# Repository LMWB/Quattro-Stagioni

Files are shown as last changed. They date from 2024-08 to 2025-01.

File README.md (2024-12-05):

# Quattro-Stagioni
RTD-Sensor Breakoutboard and C-Library

# Abstract
RTD stands for Resistance Temperature Detector. Most common used versions are PT100, PT1000 and KTY.

RTD Messverfahren werden von IC's implementiert wie z.B. der ADS124 von TI. Mit ca. 10€ sind diese jedoch verhaeltnismaessig preisintensiv.
RDT-Sensoren werden typischerweise mit einem konstanten Strom um die 1mA beaufschlagt und der daraus resultierende Spannungsfall wird gemessen.
Die spezifische Kennklienie gibt Aufschluss über die vorherrschende Temperatur.
Dieses einfache Messverfahren hat den Nachteil, dass im interesanten Wertebereich von ca. 0 bis 70 •C nur ein sehr geringer Spannungshub von ca. 250 mV entsteht (abhaengig vom gewaehlten erregerstrom, je kleiner um so besser um die Eigenerwaermung im Sensor zu vermeiden). Die Kurve R = f(T) ist also sehr flach. 
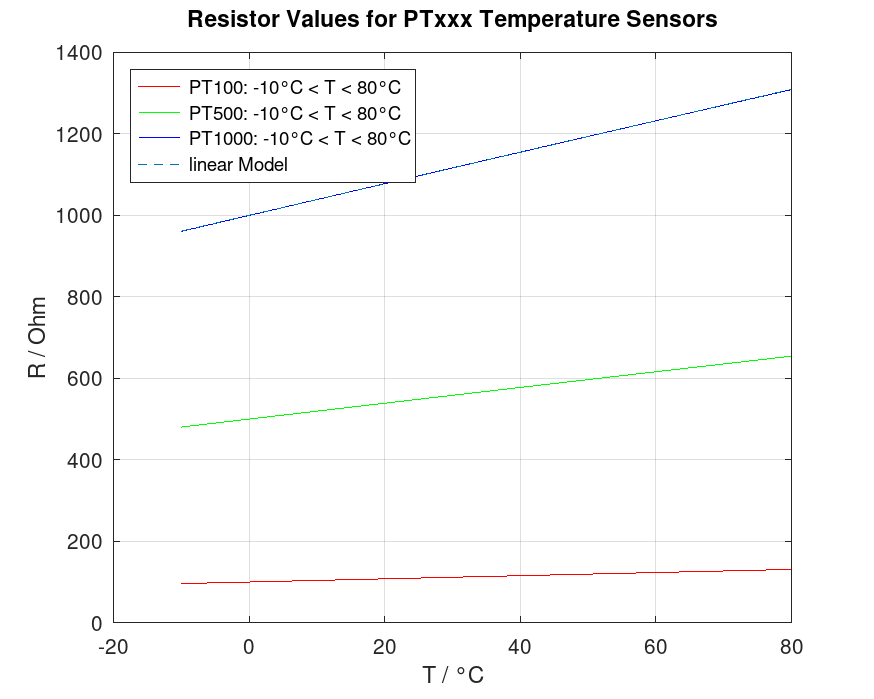
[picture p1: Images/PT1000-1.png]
RTC Function

Es erfordert einen sehr hochauflösenden ADC (16bit oder mehr) um einen entsprechenden Ausschlag zu messen.
Ein weitere Nachteil ist, dass die Referenzspannung des ADC nur in einem sehr kleinen Arbeitsbereich verwendet wird.
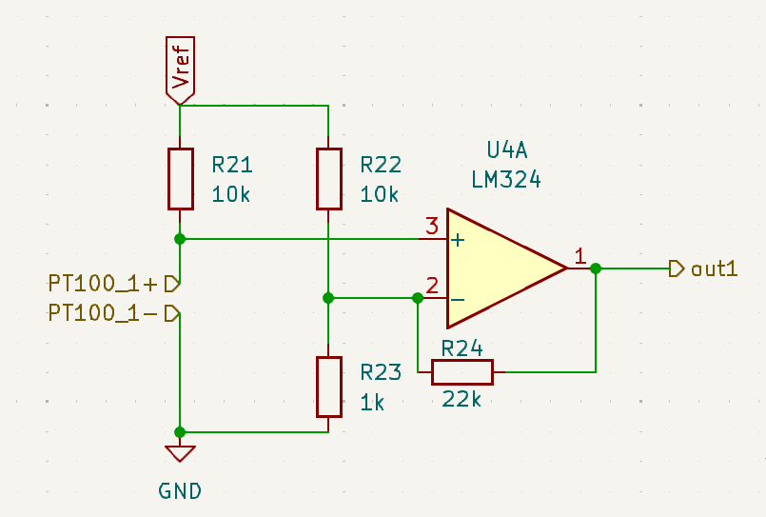
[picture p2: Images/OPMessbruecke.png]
Messverstaerker

Abhilfe schafft eine einfache Verstärkerschaltung mit einem unipolarem Operationsverstaerker.
Dieses hier vorgestellte analoge Eingangsstufe kann auch für andere physikalische Größen verwendet werden wie z.B. Ladekennlinie moderne Akkus welche von Natur aus sehr flach sind.

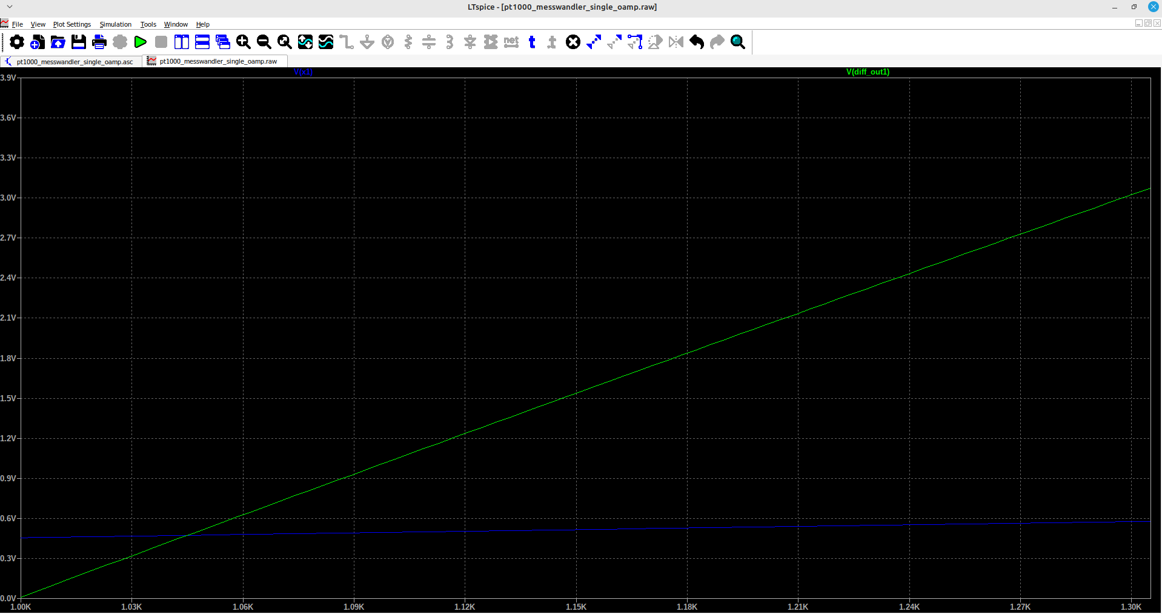
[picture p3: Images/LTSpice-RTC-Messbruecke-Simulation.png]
LTSpice Simulation Messbruecke

- blue without gain amplifier
- green with gain amplifier

Die oben beschriebene Schaltung wurde im Formfaktor eines vereinfachten Arduino-Shield realisiert. Die Platine implementier 4 Messkanaele da ein 4-fach OP verwendet wurde.
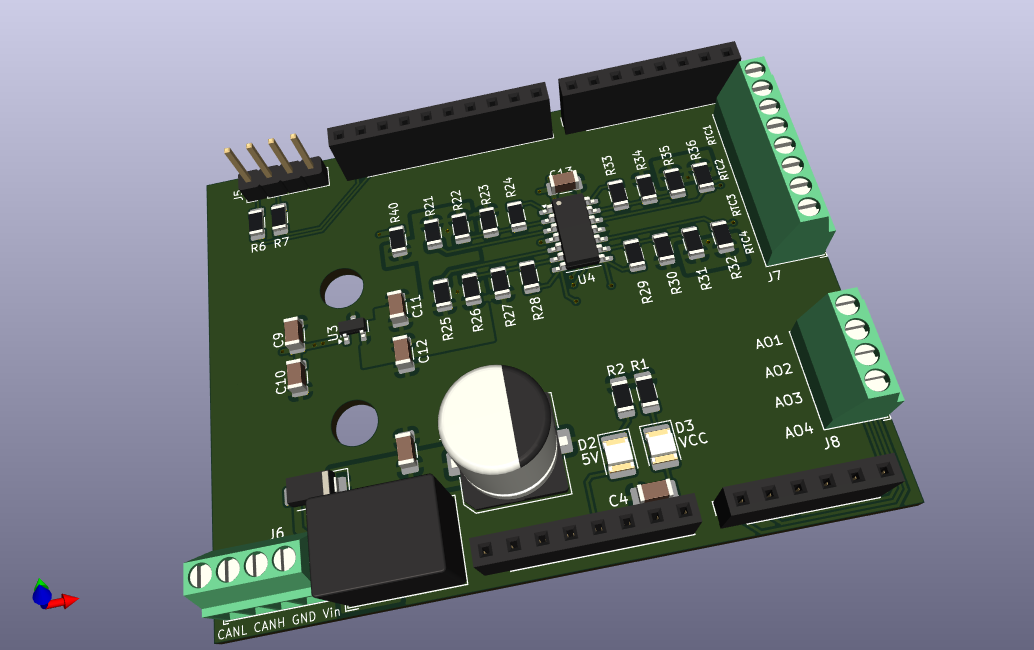
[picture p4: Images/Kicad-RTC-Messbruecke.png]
Arduino compatible breakout


# Documentation
[PCB Design and Gerber Files](/Hardware/)  
[Simulations and Models](/Simulations/)  
[Microcontroller based C-Code](/Software/)  
[BOM and costs](/Hardware/)  
[Results and Discussion](/Testing/)  

# Todo
- translate to english
- solder PCB
- testing
- reference measurement
- add CAN or Modbus to PCB

# Some Web Links
[Widerstandsthermometer / Pt100 Fühler](https://www.tcgmbh.de/widerstandsthermometer/pt100-fuehler.html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)  
[Wissenswertes über RTDs](https://www.te.com/de/products/sensors/temperature-sensors/resources/understanding-rtds.html)  
[ADS124 at mouser.com](https://www.mouser.de/ProductDetail/Texas-Instruments/ADS124S08IPBSR?qs=Bho%2FbeBaDEw8zBU%2F9K2heg%3D%3D)  

# Sorces
Wolf-Dieter Schmidt, Sensorschaltungstechnik, Elektronik 8, Vogel Fachbuch, Linearisierung von Silizium-Widerstandssensoren, S. 71

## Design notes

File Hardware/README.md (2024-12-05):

# Hardware Description
todo
# BOM and costs
Estimation of costs for RDC Sensor Board with four channels. Prizing from mouser.com 100 pieces. This calculation considers only parts relevant for the measurement bridge to make it comparable.  

| Part | Quantities | Cost per unit (Euro) | Cost total |
| --- | --- | --- | --- |
| LM324 Operational Amplifier | 1 | 0,08 | 0.08  |
| REF195 Reference Voltage Source  | 1 | 3,11 | 3.11  |
| Decoupling Capacity | 5 | 0,07 (WE) | 0,35  |
| Resistor 1% | 16 | 0,01 (Vishay) | 0,16  |

In Total: 3.7 Euro where the reference voltage is the most expensive part. 

In comparison to a quite popular approach using the ADS124S08 integrated RCD Measurement ADC from Texas Instruments. 

| Part | Quantities | Cost per unit (Euro) | Cost total |
| --- | --- | --- | --- |
| ADS124s 24-Bit ADC | 1 | 6,55 | |
| Decoupling Capacity | | | |
| Resistor 1% | | | |

In Total: 6,55 Euro  
With LM324 sampling is much faster since its four channels in parallel where as the ADS124 has to multiplex, but with the ADS124 approach data is already in digital format.

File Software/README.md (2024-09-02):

# C-Code for STM32 Microcontroller 
todo

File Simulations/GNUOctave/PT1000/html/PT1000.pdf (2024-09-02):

PT1000

## Contents

- Vergleich Kennlinie für Temperatur Sensoren PT100, PT500 & PT1000
- Berechnung der Kennlinien für Sensoren PTxxx
- Darstellung der Ergebnisse
- Fehlerbetrachtung des liniearen PT1000 Models
- Praxis
- PT1000 Nachbildung mit Widerstands Netzwerk
- Quelle

clc;clear;close;

## Vergleich Kennlinie für Temperatur Sensoren PT100, PT500 & PT1000

%
% PTxxx Sensoren sind nach DIN EN 60751 genormt. Die Kennlinie lautet

Die Werte der Koffizienten lauten (Einheit unbekannt, wurden leider in den Quellen auch nicht angegeben)

A = 3.90802 * 1e-3;
B = -5.802 * 1e-7;
C = -4.2735 * 1e-12;

Die Widerstandswerten in Ohm bei 0°C lauten

R0_100 = 100;
R0_500 = 500;
R0_1000 = 1000;

## Berechnung der Kennlinien für Sensoren PTxxx

Laufvariable (X-Achse): Temperatur der beiden Definitionsbereiche in der Einheit °C in 1° Schritten. Betrachtet wird ein technisch sinnvoller Bereich aus der Gebaudetechnik.

t1 = -10 : 1 : 0;
t2 = 0 : 1 : 80;

Definition eines Funktionshandler [t = Laufvariable Temperatur] und Berechnung der Kennlinien

f1 = @(R0, A, B, C, t) (R0 * (1 + A .* t + B .* t.^2 + C .* [t - 100] .* t.^3 )); f2 = @(R0, A, B, C, t) (R0 * (1 + A * t + B * t.^2));

R_100_1 = f1(R0_100, A, B, C, t1);
R_100_2 = f2(R0_100, A, B, C, t2);

R_500_1 = f1(R0_500, A, B, C, t1); R_500_2 = f2(R0_500, A, B, C, t2);

RPT xx(T) = { R0 ∗ (1 + A ∗ T + B ∗ T ² + C ∗ [T − 100] ∗ T ³) , −50 < T < 0°C
R0 ∗ (1 + A ∗ T + B ∗ T ²) , | 0 < T < 600°C | (1)
PT1000 | file:///home/lukas/work/git/LMWB/Quattro-Stagioni/Si...
1 of 6 | 9/2/24, 20:25

R_1000_1 = f1(R0_1000, A, B, C, t1);
R_1000_2 = f2(R0_1000, A, B, C, t2);

linKoef = polyfit( [t1, t2], [R_1000_1, R_1000_2], 1 ); lin = [t1, t2] * linKoef(1) + linKoef(2);
slope = linKoef(1)
offsett = linKoef(2)

slope = 3.8676
offsett = 1000.3

## Darstellung der Ergebnisse

Ein lineares Model der PT1000 Kennline ist ebenfalls in der Graphik eingezeichnet. Die Linearisierung der PT1000 Kennline ist erstaunlich deckungsgleich.

figure()
plot([t1, t2], [R_100_1, R_100_2], 'r') hold on
plot([t1, t2], [R_500_1, R_500_2], 'g') plot([t1, t2], [R_1000_1, R_1000_2], 'b') plot([t1, t2], lin, '--')
grid on;
hold off;

title(['Resistor Values for PTxxx Temperature Sensors']) xlabel('T / °C')
ylabel('R / Ohm')
l1 = sprintf('PT100: %d°C < T < %d°C', min(t1), max(t2)); l2 = sprintf('PT500: %d°C < T < %d°C', min(t1), max(t2)); l3 = sprintf('PT1000: %d°C < T < %d°C', min(t1), max(t2)); legend( l1,l2,l3,'linear Model', 'Location', 'NorthWest')

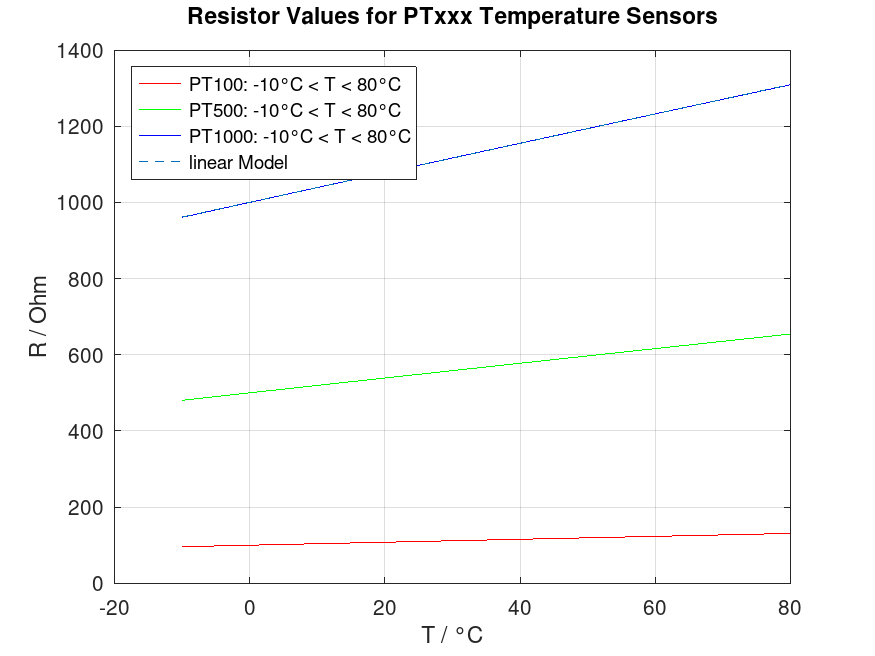
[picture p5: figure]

## Fehlerbetrachtung des liniearen PT1000 Models

errAbs = [R_1000_1, R_1000_2]-lin;
sprintf('Der maximale, absolute Fehler betraegt nur %d Ohm', max(abs(errAbs)))

figure()
plot([t1, t2], abs(errAbs));
grid on;
title(['abs. Fehler linares Model'])
xlabel('T / °C')
ylabel('R / Ohm')

ans = Der maximale, absolute Fehler betraegt nur 0.77884 Ohm

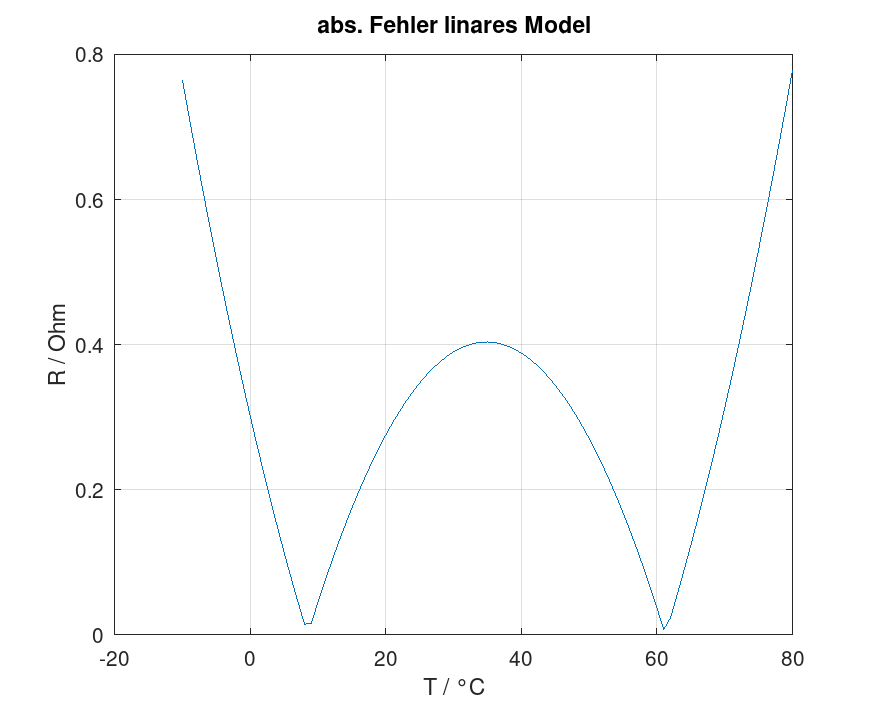
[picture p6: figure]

## Praxis

Fuer die Temperaturmessung in der Praxis, mit Hilfe eines geeigneten IC zur Auswertung (z.B ADS124 der Firma Texas Instruments) und Microcontroller ist eine Wandlung der gemessenen Spannung (indirekte Messung des elektrischen Widerstandes des PT1000 ) in Temperatur notwendig. Es gilt also die Beziehung T = f®. Dementsprechend muessen X und Y Achse getauscht werden.

linKoef = polyfit( [R_1000_1, R_1000_2], [t1, t2], 1 );
lin = [R_1000_1, R_1000_2] * linKoef(1) + linKoef(2); slope = linKoef(1)
offsett = linKoef(2)

figure()
plot([R_1000_1, R_1000_2], [t1, t2], 'r'); hold on;
plot([R_1000_1, R_1000_2], lin, '--'); grid on;
hold off;
xlabel('R / Ohm')
ylabel('T / °C')
title(['T = f(R)'])

slope = 0.2586
offsett = -258.63

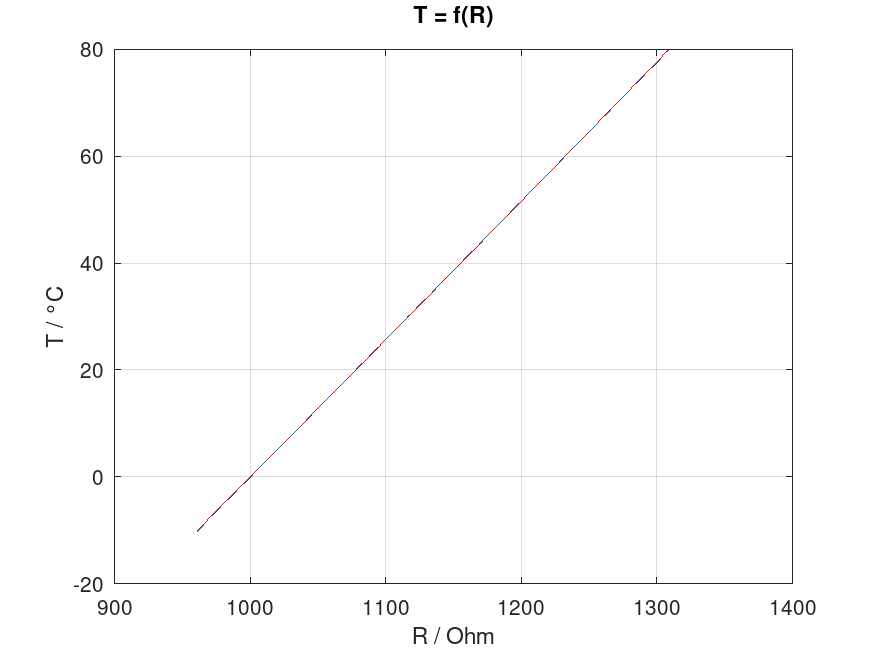
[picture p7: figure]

Auch hier entsteht ein Fehler aufgrund der Linearisierung.

errAbs = [t1, t2]-lin;
sprintf('Dieser betraegt maximal %d °C', max(abs(errAbs)))

figure()
plot([R_1000_1, R_1000_2], abs(errAbs));
grid on;
title(['abs. Fehler linares Model']) xlabel('R / Ohm')
ylabel('T / °C')

ans = Dieser betraegt maximal 0.201932 °C

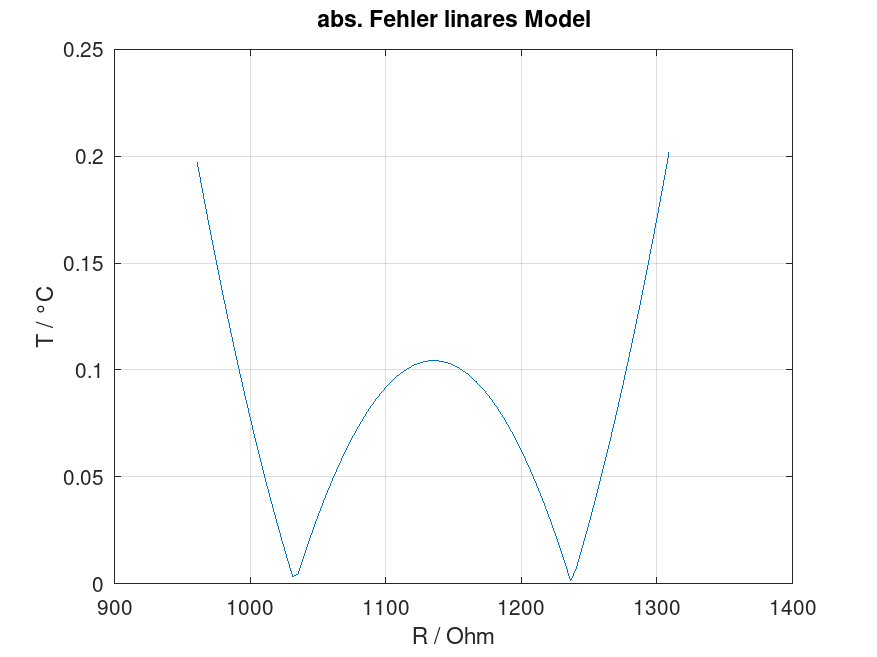
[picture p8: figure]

## PT1000 Nachbildung mit Widerstands Netzwerk

Es gibt die Ueberlegung einen PTxxx Sensor durch einen "inteligenten, elektronischen Widerstand" nachzubilden. Dieser koennte, mit einer kommunikations Schnittstelle versehen, an eine Bestehende Gebaeudetechnik Installation angebracht werden um so z.B. in die Brenner Regelung einzugreifen (Der Steuerung simulieren die Boilertemp. wäre bei 60°C und sie müsse nix tun, dabei ist die tatsächliche Temperatur viel niedriger und der z.B. Sonnenkollektor oder die Wärmepumpe füttern den Puffer)

Die fuer die Gebauedetechnik relevanten Temperaturen sind 0°C bis 100°C was bei Verwendung eines PT1000 die Widerstandswerte von ca. 1000 Ohm ... 1500 Ohm entspricht. Ein Digital Poti (zB. MCP41HV51) wird allerdings Angeboten in den Abstufungen 5k, 10k, 50k, 100k. es bedarf also eines weiterne, parallelen Widerstandsnetzwerk.

Rv = 1e3; | % Vorwiderstand
R11 = 5e3; | % Parallelwiderstand
R12 = 1e3; | % Parallelwiderstand
Rp = 0:1:5e3; % Laufvariable Digital Poti

Notiz: Zu unterscheiden wäre noch die Auswertung der temperaturabhängigen Spannung. Wird diese tatsächlich mittels konst. Messtrom durch einen Widerstand (PTxxx) realisiert mit Sicherheitsüberwacheung, dass wirklich Strom fliesst, oder handelt es sich lediglich um einen triviale Spannungsmessung. Bei letzterem Ansatz kann die aufwendige PTxxx Nachbildung entfallen und einfach nur ein Digital to Analog Converter (DAC) zum Einsatz kommen.

RPT = RV + ( + )

1
(2) 1
R1

1
Rp

Rg1 = Rv + (R11.*Rp./(R11+Rp)); Rg2 = Rv + (R12.*Rp./(R12+Rp)); figure()
plot(Rp, Rg1)
hold on
plot(Rp, Rg2)
title(['Nachbildung PTxxx Temp.-Sensors mittels digital Poti und Vorwiderstand']) ylabel('Rg / Ohm')
xlabel('R Poti / Ohm')
legend(
['R1 = ' num2str(R11) ' Ohm'], ['R1 = ' num2str(R12) ' Ohm'], 'Location', 'NorthWest')

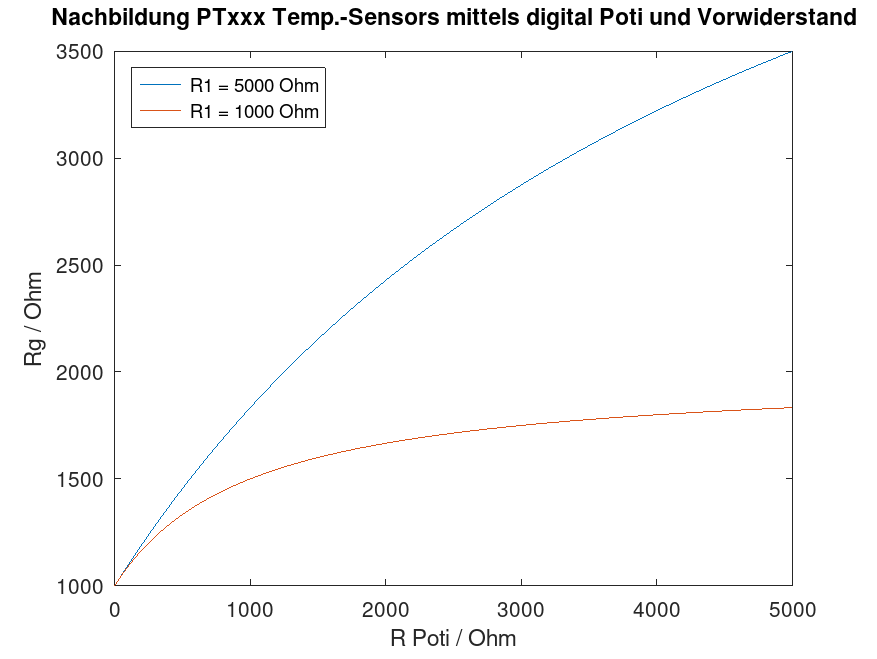
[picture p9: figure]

## Quelle

https://m.reissmann.com/fileadmin/templates/_media/produkte/pdf/st_pt_100_de.pdf https://temperatur-profis.de/temperaturfuehler/pt100-oder-pt1000/

Empfohlener Messstrom: 1mA PT100 / 0,5mA PT500 / 0,3mA PT1000 (Eigenerwärmung muss berücksichtigt werden)

% f2 = @(Rv, R1, x) (Rv + (R1 ./ (R1./x + 1)));
% f1 = @(Rv, R1, x) (Rv + (R1*x ./ (R1+x)));

SmartCube 360 GmbH Lukas Bartels 2024

Published with GNU Octave 6.4.0 (https://www.octave.org/)

RPT = RV + ⎛
⎝

⎞
⎠ | (3) 1
+ ¹
R1

1
Rp

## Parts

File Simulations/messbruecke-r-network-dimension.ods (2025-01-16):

R1 | 10000 | Ohm
RL | 10000
RTU | 921.6 | PT1000 @ -20Grad
RTM | 1136 | PT1000 @ 35Grad
RTO | 1270 | PT1000 @ 70Grad
V | 25 | Gain
R3 | 21095.81 | Ohm
R2 | 963.70 | Ohm

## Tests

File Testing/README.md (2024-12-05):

# Testing, Measurements & Results
## Setup
In the test setup I make use of [DS18B20 sensor board](https://github.com/LMWB/Quattro-Formaggi) as a reference temperature.
The DS18B20 is a well documented digital temperature sensor.
Since it is factory calibrated, I can assume it's measurements are exact (in terms of consumer market quality).
So I use the results of the DS18B20 to estimate how good my measurement bridge is working. 

I than use a rubber band to attache one DS18B20 to one PT1000 sensor. I did this twice. On pair is going to do a *hot to room temperature test*. The other pair is doing a *cold to room temperature test*. I use a metal small pitcher filled with hot water from the kettle. And I use thermal pack from the freezer. Both gets equipped with one pair of temperature sensors.

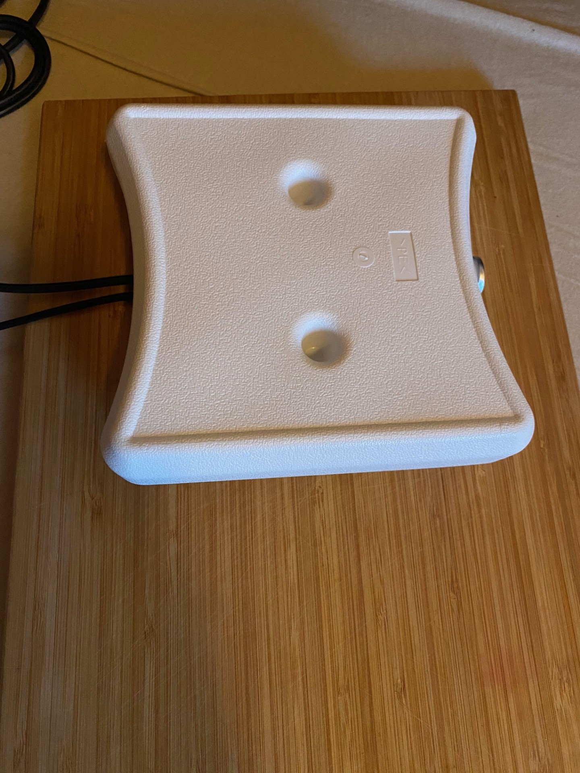
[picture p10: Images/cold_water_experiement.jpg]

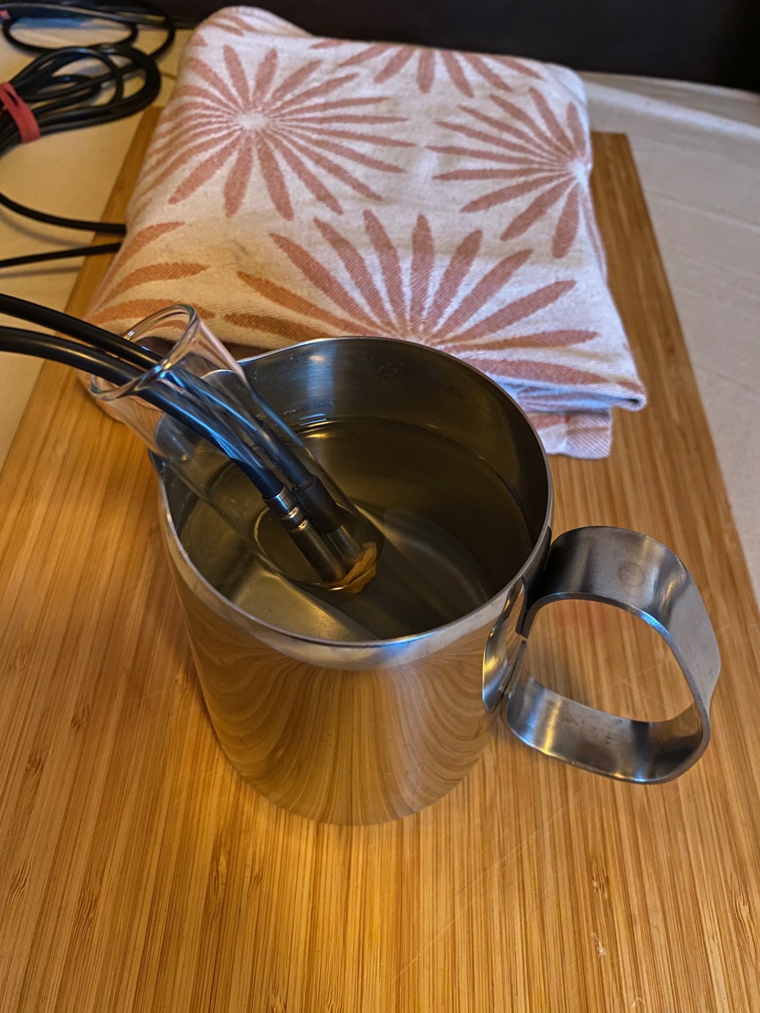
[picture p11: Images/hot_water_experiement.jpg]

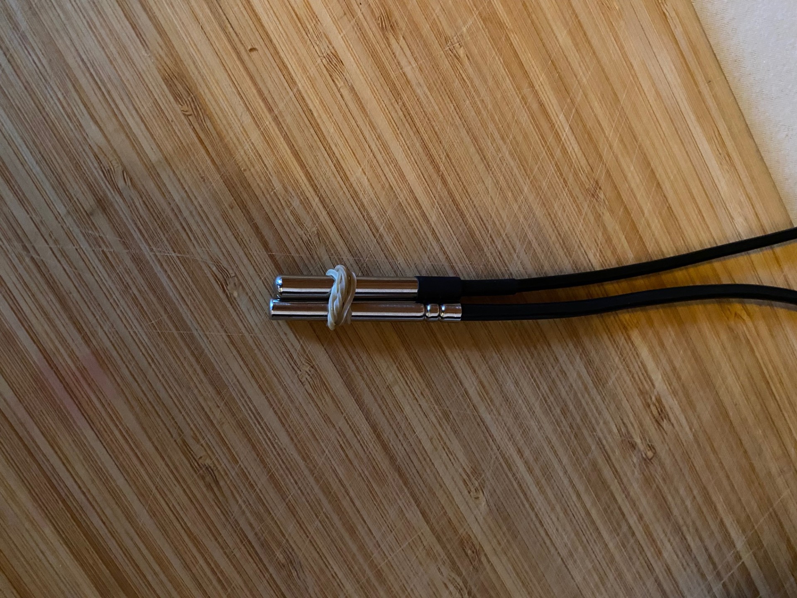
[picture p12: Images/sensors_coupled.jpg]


## Execution
To start the testing scene I only had to plug in the two Nucleo boards to my computer and start a serial terminal to log the outputs to console.
I used CuteCom. The firmware of each Nucleo board prints the temperature conversion results to serial monitor with 5000ms period (f=0.2Hz).
Total record time is T = N/f = 15540/0.2Hz = 77700 sec = 21h:30min.

## Interpretation
Study the plots two things are to mention: 
- the measurement bridge (blue line) is much noisy 
- red line and blue line are quit identical except below zero degrees Celsius

The glitch in the cold record at around 3800 ms is due to my impatience.
I lifted the thermal pack to feel the cold with my hand.
At least I could verify that both type of sensors a quick in response :).

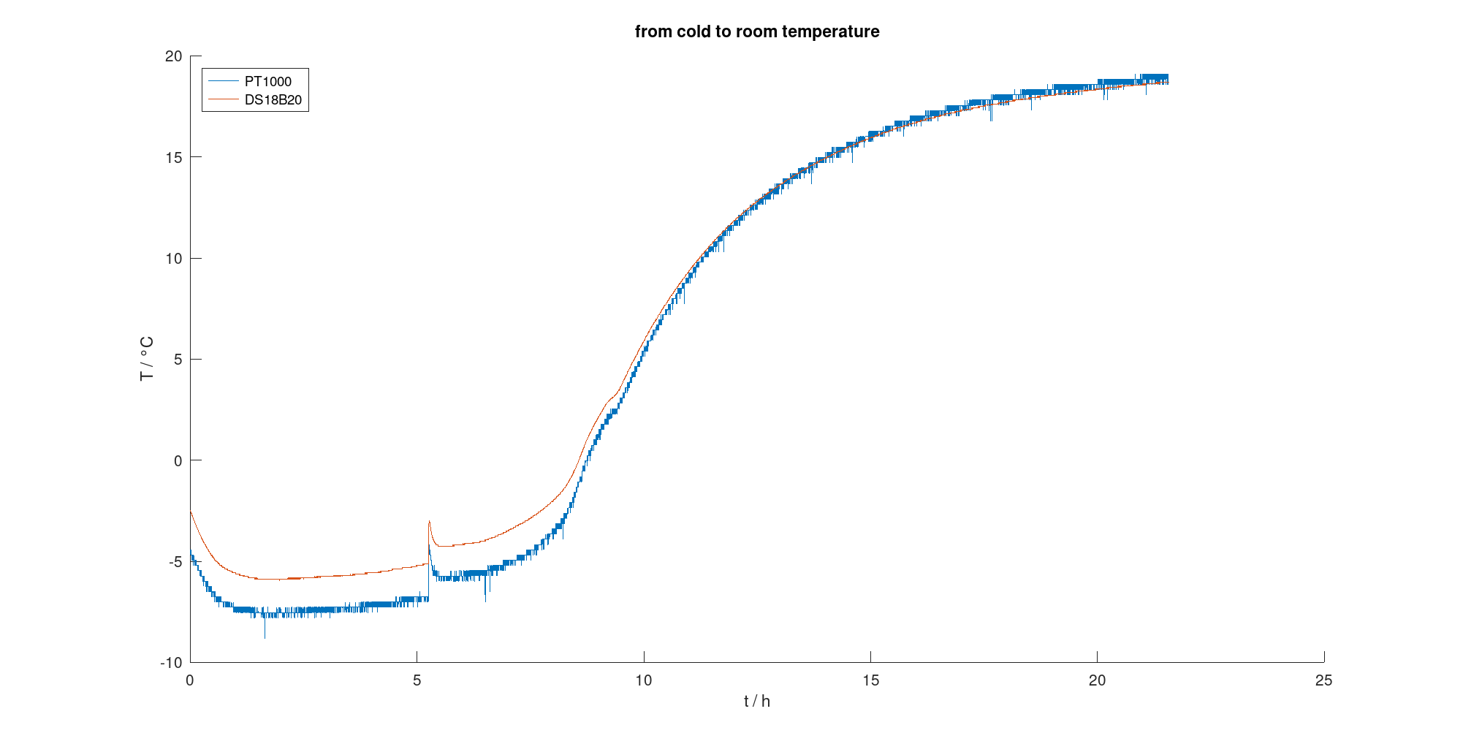
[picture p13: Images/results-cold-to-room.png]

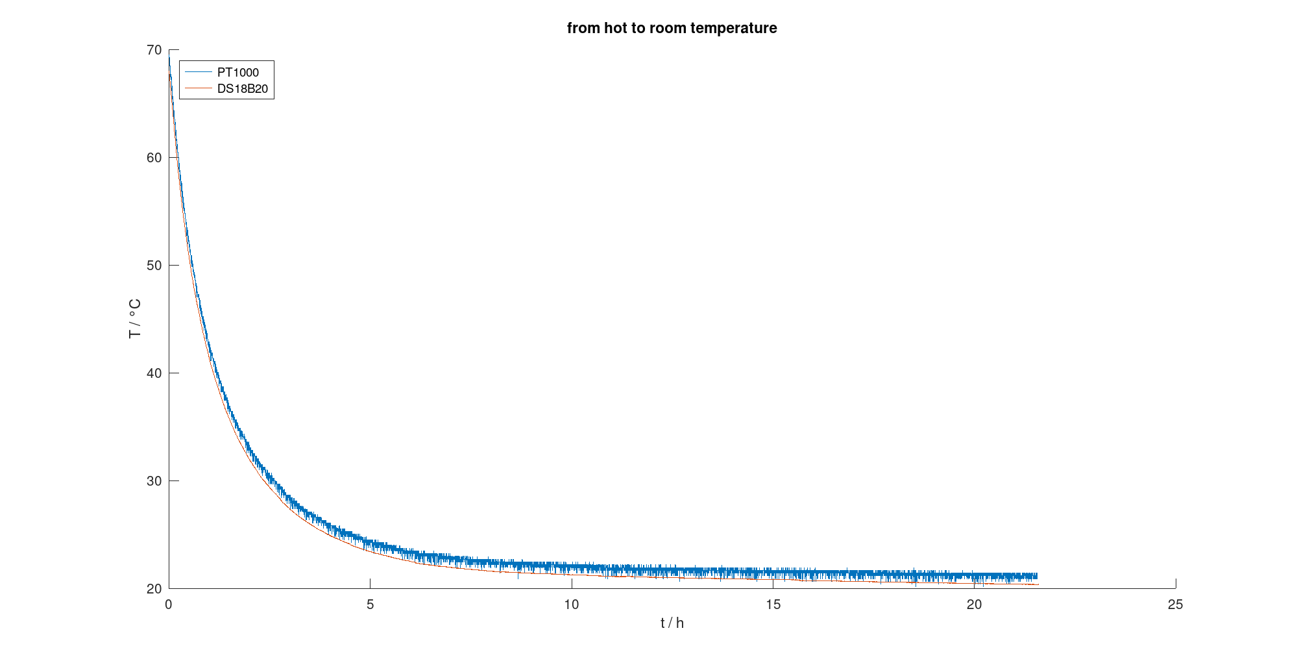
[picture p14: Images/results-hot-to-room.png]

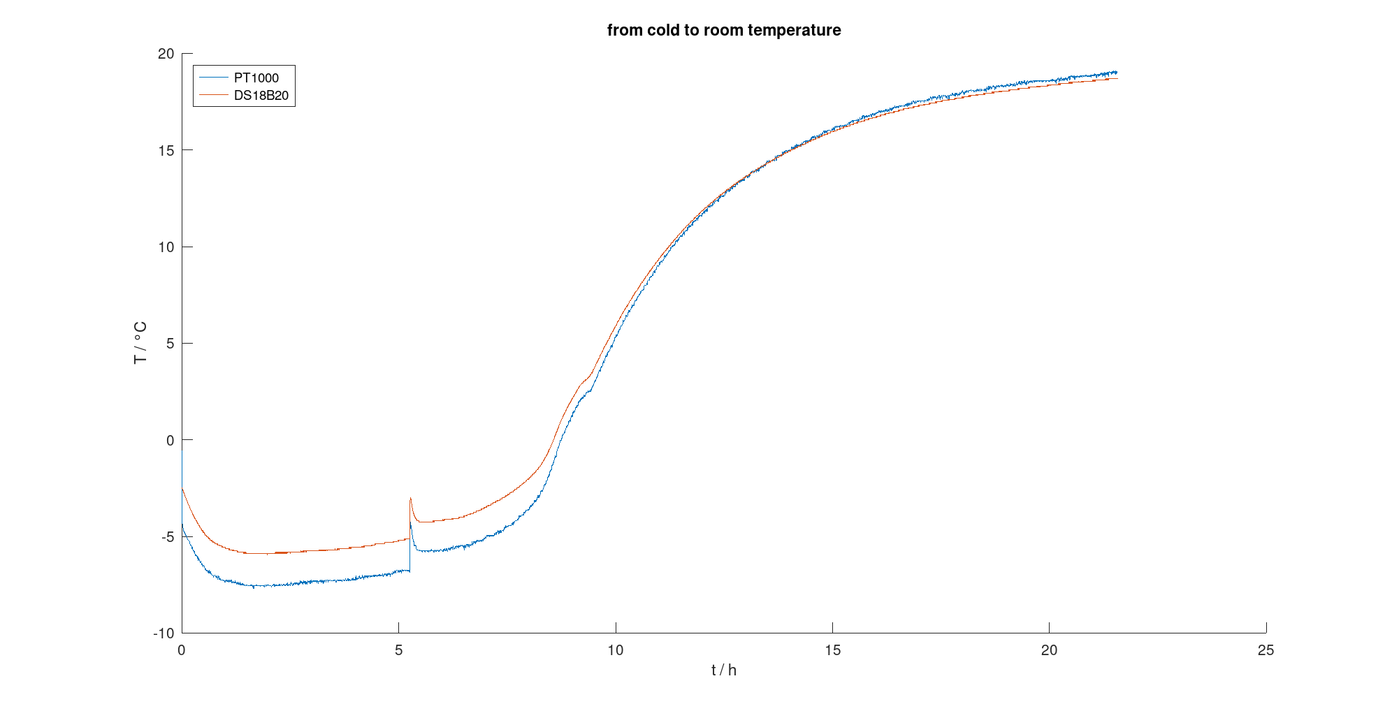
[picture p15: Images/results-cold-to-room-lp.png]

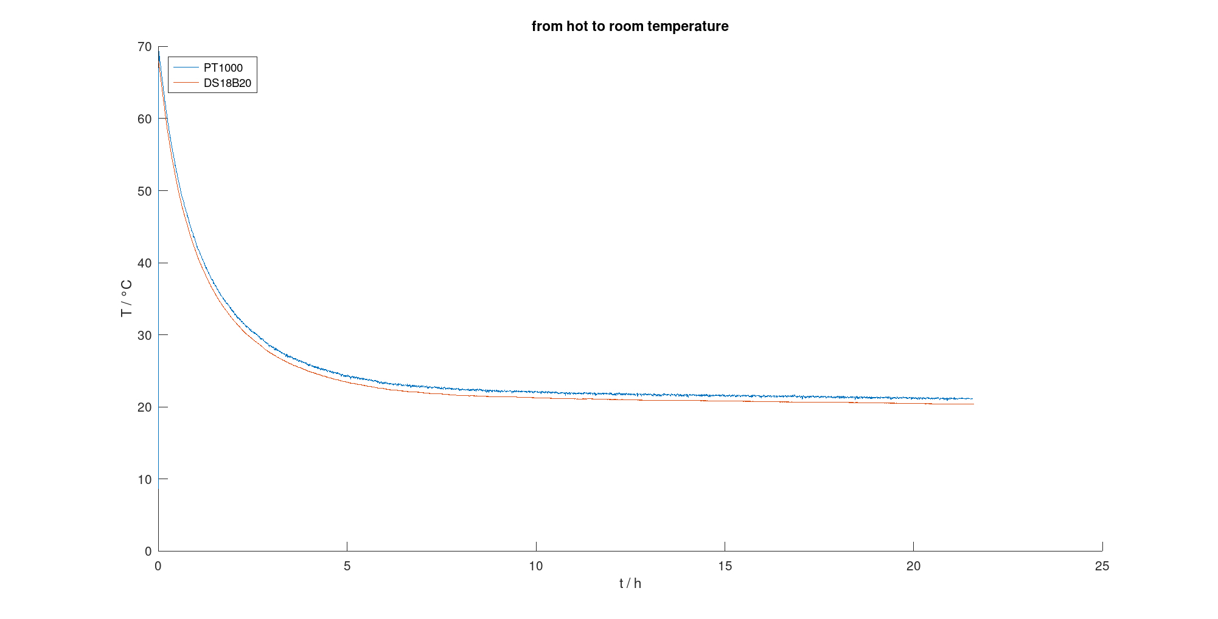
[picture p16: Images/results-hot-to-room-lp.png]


- to smooth the measurements I added a moving-average filter in Octave
- recap the schematics and the simulation done there it is clear, that this circuit is not gonna work for temperatures below zero, so the behavior is quit as expected
- to measure temperatures below zero the OPAMP must be provided with negative supply voltage or the output range must be set to cover some degrees below zero (map to positve) with some drawback of resolution on the ADC

## Error
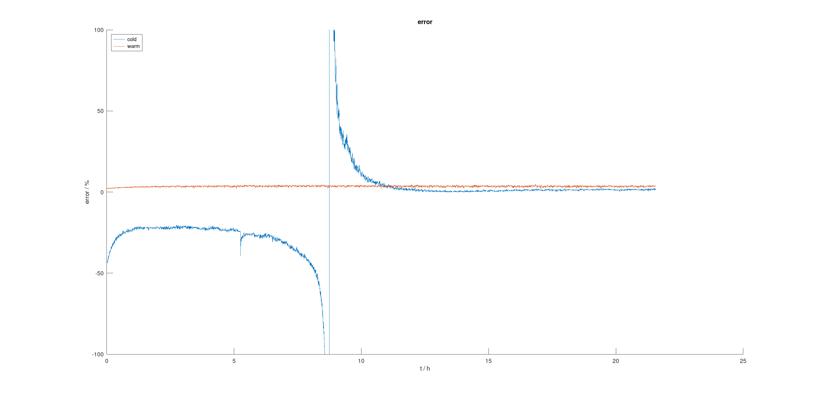
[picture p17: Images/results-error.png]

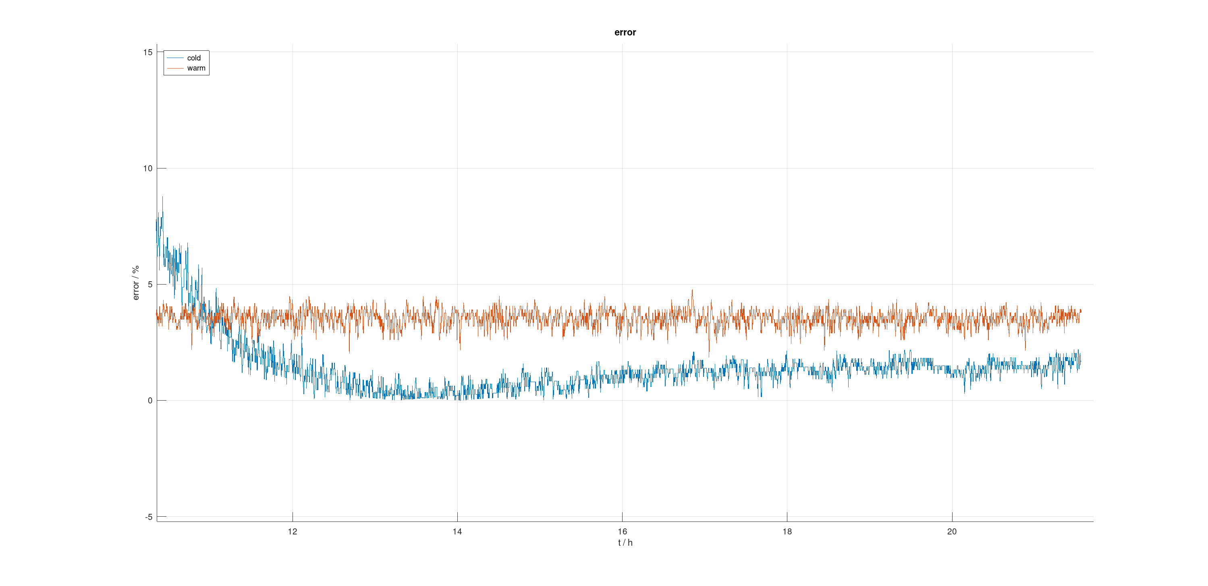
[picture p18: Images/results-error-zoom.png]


- error below zero degrees (from 0h to around 11h in time domain) is insane, but not relevant (see discussion above)
- from 10 degrees and up its very acceptable for such a primitive schematics
- the PCB fabricated so far does not have a voltage reference of 5V instead using the Nucleo onboard LDO which does not provide a stable 5V
- instead its around 4,75V
- fixing this issue will increase performance and systematic error

Perhaps the reade noticed the asymptote at x=8.7h. General formula to relative error calculation

```math
err = \frac{|y_{true}-y|}{y}
```
But what if y is zero? I mean 0 as a true value.
In my case zero degrees, which is a correct measurement.
The error goes wild since its been divided by zero. 
Does anybody know how to tread this situation in terms of correct subject to math / physics?

## Conclusions
- performance is good and as aspect from simulations
- BOM has less, uncomplicated and cheap components
- add some sort of digital low pass filter in C-code
- add reference voltage and do measurements again

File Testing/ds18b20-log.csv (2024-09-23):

tick | 5000 | DS18B20_1 | -2500 | GradC | DS18B20_2 | 68000 | GradC | DS18B20_3 | 20875 | GradC | DS18B20_4 | 21062 | GradC
tick | 10000 | DS18B20_1 | -2500 | GradC | DS18B20_2 | 68000 | GradC | DS18B20_3 | 20875 | GradC | DS18B20_4 | 21062 | GradC
tick | 15000 | DS18B20_1 | -2500 | GradC | DS18B20_2 | 67937 | GradC | DS18B20_3 | 20937 | GradC | DS18B20_4 | 21062 | GradC
tick | 20000 | DS18B20_1 | -2500 | GradC | DS18B20_2 | 67875 | GradC | DS18B20_3 | 20875 | GradC | DS18B20_4 | 21062 | GradC
tick | 25000 | DS18B20_1 | -2500 | GradC | DS18B20_2 | 67812 | GradC | DS18B20_3 | 20937 | GradC | DS18B20_4 | 21125 | GradC
tick | 30000 | DS18B20_1 | -2500 | GradC | DS18B20_2 | 67812 | GradC | DS18B20_3 | 20937 | GradC | DS18B20_4 | 21125 | GradC
tick | 35000 | DS18B20_1 | -2500 | GradC | DS18B20_2 | 67750 | GradC | DS18B20_3 | 20937 | GradC | DS18B20_4 | 21125 | GradC
tick | 40000 | DS18B20_1 | -2562 | GradC | DS18B20_2 | 67687 | GradC | DS18B20_3 | 20937 | GradC | DS18B20_4 | 21125 | GradC
tick | 45032 | DS18B20_1 | -2562 | GradC | DS18B20_2 | 67625 | GradC | DS18B20_3 | 20937 | GradC | DS18B20_4 | 21125 | GradC
tick | 50032 | DS18B20_1 | -2562 | GradC | DS18B20_2 | 67625 | GradC | DS18B20_3 | 20937 | GradC | DS18B20_4 | 21125 | GradC
tick | 55032 | DS18B20_1 | -2562 | GradC | DS18B20_2 | 67562 | GradC | DS18B20_3 | 20937 | GradC | DS18B20_4 | 21125 | GradC
tick | 60032 | DS18B20_1 | -2562 | GradC | DS18B20_2 | 67500 | GradC | DS18B20_3 | 20937 | GradC | DS18B20_4 | 21125 | GradC
tick | 65032 | DS18B20_1 | -2562 | GradC | DS18B20_2 | 67437 | GradC | DS18B20_3 | 20937 | GradC | DS18B20_4 | 21125 | GradC
tick | 70032 | DS18B20_1 | -2562 | GradC | DS18B20_2 | 67375 | GradC | DS18B20_3 | 20937 | GradC | DS18B20_4 | 21125 | GradC
tick | 75032 | DS18B20_1 | -2562 | GradC | DS18B20_2 | 67312 | GradC | DS18B20_3 | 20937 | GradC | DS18B20_4 | 21125 | GradC
tick | 80032 | DS18B20_1 | -2562 | GradC | DS18B20_2 | 67250 | GradC | DS18B20_3 | 20937 | GradC | DS18B20_4 | 21125 | GradC
tick | 85032 | DS18B20_1 | -2562 | GradC | DS18B20_2 | 67250 | GradC | DS18B20_3 | 20937 | GradC | DS18B20_4 | 21125 | GradC
tick | 90032 | DS18B20_1 | -2625 | GradC | DS18B20_2 | 67187 | GradC | DS18B20_3 | 20937 | GradC | DS18B20_4 | 21125 | GradC
tick | 95032 | DS18B20_1 | -2625 | GradC | DS18B20_2 | 67062 | GradC | DS18B20_3 | 20937 | GradC | DS18B20_4 | 21187 | GradC
tick | 100032 | DS18B20_1 | -2625 | GradC | DS18B20_2 | 67062 | GradC | DS18B20_3 | 21000 | GradC | DS18B20_4 | 21187 | GradC
tick | 105032 | DS18B20_1 | -2625 | GradC | DS18B20_2 | 67000 | GradC | DS18B20_3 | 21000 | GradC | DS18B20_4 | 21187 | GradC
tick | 110032 | DS18B20_1 | -2625 | GradC | DS18B20_2 | 66937 | GradC | DS18B20_3 | 21000 | GradC | DS18B20_4 | 21187 | GradC
tick | 115032 | DS18B20_1 | -2625 | GradC | DS18B20_2 | 66875 | GradC | DS18B20_3 | 21000 | GradC | DS18B20_4 | 21187 | GradC
tick | 120032 | DS18B20_1 | -2687 | GradC | DS18B20_2 | 66812 | GradC | DS18B20_3 | 21000 | GradC | DS18B20_4 | 21187 | GradC
tick | 125032 | DS18B20_1 | -2687 | GradC | DS18B20_2 | 66750 | GradC | DS18B20_3 | 21000 | GradC | DS18B20_4 | 21187 | GradC
tick | 130032 | DS18B20_1 | -2687 | GradC | DS18B20_2 | 66687 | GradC | DS18B20_3 | 21000 | GradC | DS18B20_4 | 21187 | GradC
tick | 135032 | DS18B20_1 | -2687 | GradC | DS18B20_2 | 66687 | GradC | DS18B20_3 | 21000 | GradC | DS18B20_4 | 21187 | GradC
tick | 140032 | DS18B20_1 | -2687 | GradC | DS18B20_2 | 66562 | GradC | DS18B20_3 | 21000 | GradC | DS18B20_4 | 21187 | GradC
tick | 145032 | DS18B20_1 | -2687 | GradC | DS18B20_2 | 66562 | GradC | DS18B20_3 | 21000 | GradC | DS18B20_4 | 21187 | GradC
tick | 150032 | DS18B20_1 | -2750 | GradC | DS18B20_2 | 66500 | GradC | DS18B20_3 | 21000 | GradC | DS18B20_4 | 21187 | GradC
tick | 155032 | DS18B20_1 | -2750 | GradC | DS18B20_2 | 66437 | GradC | DS18B20_3 | 21000 | GradC | DS18B20_4 | 21187 | GradC
tick | 160044 | DS18B20_1 | -2750 | GradC | DS18B20_2 | 66375 | GradC | DS18B20_3 | 21000 | GradC | DS18B20_4 | 21187 | GradC
tick | 165044 | DS18B20_1 | -2750 | GradC | DS18B20_2 | 66312 | GradC | DS18B20_3 | 21000 | GradC | DS18B20_4 | 21187 | GradC
tick | 170044 | DS18B20_1 | -2750 | GradC | DS18B20_2 | 66250 | GradC | DS18B20_3 | 21000 | GradC | DS18B20_4 | 21187 | GradC
tick | 175044 | DS18B20_1 | -2750 | GradC | DS18B20_2 | 66187 | GradC | DS18B20_3 | 21000 | GradC | DS18B20_4 | 21187 | GradC
tick | 180074 | DS18B20_1 | -2750 | GradC | DS18B20_2 | 66125 | GradC | DS18B20_3 | 21000 | GradC | DS18B20_4 | 21187 | GradC
tick | 185074 | DS18B20_1 | -2812 | GradC | DS18B20_2 | 66125 | GradC | DS18B20_3 | 21000 | GradC | DS18B20_4 | 21187 | GradC
tick | 190074 | DS18B20_1 | -2812 | GradC | DS18B20_2 | 66062 | GradC | DS18B20_3 | 21000 | GradC | DS18B20_4 | 21187 | GradC
tick | 195074 | DS18B20_1 | -2812 | GradC | DS18B20_2 | 66000 | GradC | DS18B20_3 | 21000 | GradC | DS18B20_4 | 21187 | GradC
tick | 200101 | DS18B20_1 | -2812 | GradC | DS18B20_2 | 65937 | GradC | DS18B20_3 | 21000 | GradC | DS18B20_4 | 21187 | GradC
tick | 205101 | DS18B20_1 | -2812 | GradC | DS18B20_2 | 65875 | GradC | DS18B20_3 | 21000 | GradC | DS18B20_4 | 21187 | GradC
tick | 210101 | DS18B20_1 | -2812 | GradC | DS18B20_2 | 65812 | GradC | DS18B20_3 | 21000 | GradC | DS18B20_4 | 21187 | GradC
tick | 215101 | DS18B20_1 | -2812 | GradC | DS18B20_2 | 65687 | GradC | DS18B20_3 | 21000 | GradC | DS18B20_4 | 21187 | GradC
tick | 220127 | DS18B20_1 | -2875 | GradC | DS18B20_2 | 65625 | GradC | DS18B20_3 | 21000 | GradC | DS18B20_4 | 21187 | GradC
tick | 225127 | DS18B20_1 | -2875 | GradC | DS18B20_2 | 65625 | GradC | DS18B20_3 | 21000 | GradC | DS18B20_4 | 21187 | GradC
tick | 230127 | DS18B20_1 | -2875 | GradC | DS18B20_2 | 65562 | GradC | DS18B20_3 | 21000 | GradC | DS18B20_4 | 21187 | GradC
tick | 235127 | DS18B20_1 | -2875 | GradC | DS18B20_2 | 65500 | GradC | DS18B20_3 | 21000 | GradC | DS18B20_4 | 21187 | GradC
tick | 240156 | DS18B20_1 | -2875 | GradC | DS18B20_2 | 65437 | GradC | DS18B20_3 | 21000 | GradC | DS18B20_4 | 21187 | GradC
tick | 245156 | DS18B20_1 | -2875 | GradC | DS18B20_2 | 65375 | GradC | DS18B20_3 | 21000 | GradC | DS18B20_4 | 21250 | GradC
tick | 250156 | DS18B20_1 | -2875 | GradC | DS18B20_2 | 65312 | GradC | DS18B20_3 | 21000 | GradC | DS18B20_4 | 21187 | GradC
tick | 255156 | DS18B20_1 | -2875 | GradC | DS18B20_2 | 65250 | GradC | DS18B20_3 | 21000 | GradC | DS18B20_4 | 21187 | GradC
tick | 260188 | DS18B20_1 | -2937 | GradC | DS18B20_2 | 65187 | GradC | DS18B20_3 | 21000 | GradC | DS18B20_4 | 21250 | GradC
tick | 265188 | DS18B20_1 | -2937 | GradC | DS18B20_2 | 65125 | GradC | DS18B20_3 | 21000 | GradC | DS18B20_4 | 21187 | GradC
tick | 270188 | DS18B20_1 | -2937 | GradC | DS18B20_2 | 65062 | GradC | DS18B20_3 | 21000 | GradC | DS18B20_4 | 21187 | GradC
tick | 275188 | DS18B20_1 | -2937 | GradC | DS18B20_2 | 65000 | GradC | DS18B20_3 | 21000 | GradC | DS18B20_4 | 21250 | GradC
tick | 280222 | DS18B20_1 | -2937 | GradC | DS18B20_2 | 64937 | GradC | DS18B20_3 | 21000 | GradC | DS18B20_4 | 21187 | GradC
tick | 285222 | DS18B20_1 | -2937 | GradC | DS18B20_2 | 64875 | GradC | DS18B20_3 | 21000 | GradC | DS18B20_4 | 21187 | GradC
tick | 290222 | DS18B20_1 | -2937 | GradC | DS18B20_2 | 64812 | GradC | DS18B20_3 | 21000 | GradC | DS18B20_4 | 21187 | GradC
tick | 295222 | DS18B20_1 | -2937 | GradC | DS18B20_2 | 64750 | GradC | DS18B20_3 | 21000 | GradC | DS18B20_4 | 21250 | GradC
tick | 300257 | DS18B20_1 | -3000 | GradC | DS18B20_2 | 64687 | GradC | DS18B20_3 | 21000 | GradC | DS18B20_4 | 21250 | GradC
tick | 305257 | DS18B20_1 | -3000 | GradC | DS18B20_2 | 64625 | GradC | DS18B20_3 | 21000 | GradC | DS18B20_4 | 21250 | GradC
tick | 310257 | DS18B20_1 | -3000 | GradC | DS18B20_2 | 64562 | GradC | DS18B20_3 | 21000 | GradC | DS18B20_4 | 21187 | GradC
tick | 315257 | DS18B20_1 | -3000 | GradC | DS18B20_2 | 64500 | GradC | DS18B20_3 | 21062 | GradC | DS18B20_4 | 21250 | GradC
tick | 320290 | DS18B20_1 | -3000 | GradC | DS18B20_2 | 64437 | GradC | DS18B20_3 | 21000 | GradC | DS18B20_4 | 21187 | GradC
tick | 325290 | DS18B20_1 | -3000 | GradC | DS18B20_2 | 64437 | GradC | DS18B20_3 | 21000 | GradC | DS18B20_4 | 21250 | GradC
tick | 330290 | DS18B20_1 | -3000 | GradC | DS18B20_2 | 64375 | GradC | DS18B20_3 | 21000 | GradC | DS18B20_4 | 21250 | GradC
tick | 335290 | DS18B20_1 | -3062 | GradC | DS18B20_2 | 64312 | GradC | DS18B20_3 | 21000 | GradC | DS18B20_4 | 21250 | GradC
tick | 340320 | DS18B20_1 | -3062 | GradC | DS18B20_2 | 64250 | GradC | DS18B20_3 | 21000 | GradC | DS18B20_4 | 21250 | GradC
tick | 345320 | DS18B20_1 | -3062 | GradC | DS18B20_2 | 64187 | GradC | DS18B20_3 | 21000 | GradC | DS18B20_4 | 21250 | GradC
tick | 350320 | DS18B20_1 | -3062 | GradC | DS18B20_2 | 64125 | GradC | DS18B20_3 | 21000 | GradC | DS18B20_4 | 21250 | GradC
tick | 355320 | DS18B20_1 | -3062 | GradC | DS18B20_2 | 64062 | GradC | DS18B20_3 | 21000 | GradC | DS18B20_4 | 21250 | GradC
tick | 360349 | DS18B20_1 | -3062 | GradC | DS18B20_2 | 64000 | GradC | DS18B20_3 | 21000 | GradC | DS18B20_4 | 21187 | GradC
tick | 365349 | DS18B20_1 | -3062 | GradC | DS18B20_2 | 63937 | GradC | DS18B20_3 | 21000 | GradC | DS18B20_4 | 21187 | GradC
tick | 370349 | DS18B20_1 | -3062 | GradC | DS18B20_2 | 63937 | GradC | DS18B20_3 | 21000 | GradC | DS18B20_4 | 21250 | GradC
tick | 375349 | DS18B20_1 | -3062 | GradC | DS18B20_2 | 63875 | GradC | DS18B20_3 | 21000 | GradC | DS18B20_4 | 21250 | GradC
tick | 380379 | DS18B20_1 | -3125 | GradC | DS18B20_2 | 63812 | GradC | DS18B20_3 | 21000 | GradC | DS18B20_4 | 21250 | GradC
tick | 385379 | DS18B20_1 | -3125 | GradC | DS18B20_2 | 63750 | GradC | DS18B20_3 | 21000 | GradC | DS18B20_4 | 21250 | GradC
tick | 390379 | DS18B20_1 | -3125 | GradC | DS18B20_2 | 63687 | GradC | DS18B20_3 | 21000 | GradC | DS18B20_4 | 21250 | GradC
tick | 395379 | DS18B20_1 | -3125 | GradC | DS18B20_2 | 63625 | GradC | DS18B20_3 | 21000 | GradC | DS18B20_4 | 21250 | GradC
tick | 400411 | DS18B20_1 | -3125 | GradC | DS18B20_2 | 63562 | GradC | DS18B20_3 | 21000 | GradC | DS18B20_4 | 21187 | GradC
tick | 405411 | DS18B20_1 | -3125 | GradC | DS18B20_2 | 63500 | GradC | DS18B20_3 | 21000 | GradC | DS18B20_4 | 21187 | GradC
tick | 410411 | DS18B20_1 | -3125 | GradC | DS18B20_2 | 63437 | GradC | DS18B20_3 | 21000 | GradC | DS18B20_4 | 21250 | GradC
tick | 415411 | DS18B20_1 | -3125 | GradC | DS18B20_2 | 63437 | GradC | DS18B20_3 | 21000 | GradC | DS18B20_4 | 21187 | GradC
tick | 420440 | DS18B20_1 | -3187 | GradC | DS18B20_2 | 63375 | GradC | DS18B20_3 | 21000 | GradC | DS18B20_4 | 21187 | GradC
tick | 425440 | DS18B20_1 | -3187 | GradC | DS18B20_2 | 63312 | GradC | DS18B20_3 | 21000 | GradC | DS18B20_4 | 21187 | GradC
tick | 430440 | DS18B20_1 | -3187 | GradC | DS18B20_2 | 63250 | GradC | DS18B20_3 | 21000 | GradC | DS18B20_4 | 21250 | GradC
tick | 435440 | DS18B20_1 | -3187 | GradC | DS18B20_2 | 63187 | GradC | DS18B20_3 | 21000 | GradC | DS18B20_4 | 21187 | GradC
tick | 440461 | DS18B20_1 | -3187 | GradC | DS18B20_2 | 63125 | GradC | DS18B20_3 | 21000 | GradC | DS18B20_4 | 21187 | GradC
tick | 445461 | DS18B20_1 | -3187 | GradC | DS18B20_2 | 63062 | GradC | DS18B20_3 | 21000 | GradC | DS18B20_4 | 21187 | GradC
tick | 450461 | DS18B20_1 | -3187 | GradC | DS18B20_2 | 63000 | GradC | DS18B20_3 | 21000 | GradC | DS18B20_4 | 21187 | GradC
tick | 455461 | DS18B20_1 | -3187 | GradC | DS18B20_2 | 62937 | GradC | DS18B20_3 | 21000 | GradC | DS18B20_4 | 21187 | GradC
tick | 460475 | DS18B20_1 | -3250 | GradC | DS18B20_2 | 62875 | GradC | DS18B20_3 | 21000 | GradC | DS18B20_4 | 21187 | GradC
tick | 465475 | DS18B20_1 | -3250 | GradC | DS18B20_2 | 62812 | GradC | DS18B20_3 | 21000 | GradC | DS18B20_4 | 21187 | GradC
tick | 470475 | DS18B20_1 | -3250 | GradC | DS18B20_2 | 62750 | GradC | DS18B20_3 | 21000 | GradC | DS18B20_4 | 21187 | GradC
tick | 475475 | DS18B20_1 | -3250 | GradC | DS18B20_2 | 62687 | GradC | DS18B20_3 | 21000 | GradC | DS18B20_4 | 21187 | GradC
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

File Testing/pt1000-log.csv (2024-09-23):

tick | 5000 | PT1000_1 | 983 | Ohm | -4426 | GradC | PT1000_2 | 1269 | Ohm | 69533 | GradC | PT1000_3 | 1084 | Ohm | 21692 | GradC | PT1000_4 | 1081 | Ohm | 20916 | GradCCPU_Temperature | 31 | GradC
tick | 10000 | PT1000_1 | 983 | Ohm | -4426 | GradC | PT1000_2 | 1269 | Ohm | 69533 | GradC | PT1000_3 | 1083 | Ohm | 21433 | GradC | PT1000_4 | 1081 | Ohm | 20916 | GradCCPU_Temperature | 31 | GradC
tick | 15000 | PT1000_1 | 983 | Ohm | -4426 | GradC | PT1000_2 | 1268 | Ohm | 69274 | GradC | PT1000_3 | 1083 | Ohm | 21433 | GradC | PT1000_4 | 1081 | Ohm | 20916 | GradCCPU_Temperature | 31 | GradC
tick | 20000 | PT1000_1 | 983 | Ohm | -4426 | GradC | PT1000_2 | 1268 | Ohm | 69274 | GradC | PT1000_3 | 1083 | Ohm | 21433 | GradC | PT1000_4 | 1081 | Ohm | 20916 | GradCCPU_Temperature | 31 | GradC
tick | 25000 | PT1000_1 | 983 | Ohm | -4426 | GradC | PT1000_2 | 1268 | Ohm | 69274 | GradC | PT1000_3 | 1083 | Ohm | 21433 | GradC | PT1000_4 | 1081 | Ohm | 20916 | GradCCPU_Temperature | 31 | GradC
tick | 30000 | PT1000_1 | 983 | Ohm | -4426 | GradC | PT1000_2 | 1268 | Ohm | 69274 | GradC | PT1000_3 | 1083 | Ohm | 21433 | GradC | PT1000_4 | 1081 | Ohm | 20916 | GradCCPU_Temperature | 31 | GradC
tick | 35000 | PT1000_1 | 982 | Ohm | -4684 | GradC | PT1000_2 | 1268 | Ohm | 69274 | GradC | PT1000_3 | 1083 | Ohm | 21433 | GradC | PT1000_4 | 1081 | Ohm | 20916 | GradCCPU_Temperature | 31 | GradC
tick | 40000 | PT1000_1 | 982 | Ohm | -4684 | GradC | PT1000_2 | 1268 | Ohm | 69274 | GradC | PT1000_3 | 1083 | Ohm | 21433 | GradC | PT1000_4 | 1081 | Ohm | 20916 | GradCCPU_Temperature | 31 | GradC
tick | 45000 | PT1000_1 | 983 | Ohm | -4426 | GradC | PT1000_2 | 1267 | Ohm | 69016 | GradC | PT1000_3 | 1084 | Ohm | 21692 | GradC | PT1000_4 | 1081 | Ohm | 20916 | GradCCPU_Temperature | 31 | GradC
tick | 50000 | PT1000_1 | 983 | Ohm | -4426 | GradC | PT1000_2 | 1265 | Ohm | 68499 | GradC | PT1000_3 | 1083 | Ohm | 21433 | GradC | PT1000_4 | 1081 | Ohm | 20916 | GradCCPU_Temperature | 31 | GradC
tick | 55000 | PT1000_1 | 982 | Ohm | -4684 | GradC | PT1000_2 | 1266 | Ohm | 68757 | GradC | PT1000_3 | 1083 | Ohm | 21433 | GradC | PT1000_4 | 1081 | Ohm | 20916 | GradCCPU_Temperature | 30 | GradC
tick | 60000 | PT1000_1 | 982 | Ohm | -4684 | GradC | PT1000_2 | 1267 | Ohm | 69016 | GradC | PT1000_3 | 1083 | Ohm | 21433 | GradC | PT1000_4 | 1081 | Ohm | 20916 | GradCCPU_Temperature | 31 | GradC
tick | 65000 | PT1000_1 | 983 | Ohm | -4426 | GradC | PT1000_2 | 1267 | Ohm | 69016 | GradC | PT1000_3 | 1083 | Ohm | 21433 | GradC | PT1000_4 | 1081 | Ohm | 20916 | GradCCPU_Temperature | 31 | GradC
tick | 70000 | PT1000_1 | 983 | Ohm | -4426 | GradC | PT1000_2 | 1266 | Ohm | 68757 | GradC | PT1000_3 | 1083 | Ohm | 21433 | GradC | PT1000_4 | 1081 | Ohm | 20916 | GradCCPU_Temperature | 31 | GradC
tick | 75000 | PT1000_1 | 983 | Ohm | -4426 | GradC | PT1000_2 | 1266 | Ohm | 68757 | GradC | PT1000_3 | 1083 | Ohm | 21433 | GradC | PT1000_4 | 1081 | Ohm | 20916 | GradCCPU_Temperature | 31 | GradC
tick | 80000 | PT1000_1 | 982 | Ohm | -4684 | GradC | PT1000_2 | 1265 | Ohm | 68499 | GradC | PT1000_3 | 1084 | Ohm | 21692 | GradC | PT1000_4 | 1082 | Ohm | 21175 | GradCCPU_Temperature | 31 | GradC
tick | 85000 | PT1000_1 | 983 | Ohm | -4426 | GradC | PT1000_2 | 1266 | Ohm | 68757 | GradC | PT1000_3 | 1083 | Ohm | 21433 | GradC | PT1000_4 | 1081 | Ohm | 20916 | GradCCPU_Temperature | 31 | GradC
tick | 90000 | PT1000_1 | 982 | Ohm | -4684 | GradC | PT1000_2 | 1265 | Ohm | 68499 | GradC | PT1000_3 | 1084 | Ohm | 21692 | GradC | PT1000_4 | 1081 | Ohm | 20916 | GradCCPU_Temperature | 31 | GradC
tick | 95000 | PT1000_1 | 982 | Ohm | -4684 | GradC | PT1000_2 | 1265 | Ohm | 68499 | GradC | PT1000_3 | 1083 | Ohm | 21433 | GradC | PT1000_4 | 1081 | Ohm | 20916 | GradCCPU_Temperature | 31 | GradC
tick | 100000 | PT1000_1 | 982 | Ohm | -4684 | GradC | PT1000_2 | 1265 | Ohm | 68499 | GradC | PT1000_3 | 1083 | Ohm | 21433 | GradC | PT1000_4 | 1081 | Ohm | 20916 | GradCCPU_Temperature | 31 | GradC
tick | 105000 | PT1000_1 | 982 | Ohm | -4684 | GradC | PT1000_2 | 1265 | Ohm | 68499 | GradC | PT1000_3 | 1083 | Ohm | 21433 | GradC | PT1000_4 | 1081 | Ohm | 20916 | GradCCPU_Temperature | 31 | GradC
tick | 110000 | PT1000_1 | 982 | Ohm | -4684 | GradC | PT1000_2 | 1264 | Ohm | 68240 | GradC | PT1000_3 | 1083 | Ohm | 21433 | GradC | PT1000_4 | 1081 | Ohm | 20916 | GradCCPU_Temperature | 31 | GradC
tick | 115000 | PT1000_1 | 982 | Ohm | -4684 | GradC | PT1000_2 | 1264 | Ohm | 68240 | GradC | PT1000_3 | 1083 | Ohm | 21433 | GradC | PT1000_4 | 1082 | Ohm | 21175 | GradCCPU_Temperature | 30 | GradC
tick | 120000 | PT1000_1 | 982 | Ohm | -4684 | GradC | PT1000_2 | 1264 | Ohm | 68240 | GradC | PT1000_3 | 1083 | Ohm | 21433 | GradC | PT1000_4 | 1081 | Ohm | 20916 | GradCCPU_Temperature | 31 | GradC
tick | 125000 | PT1000_1 | 982 | Ohm | -4684 | GradC | PT1000_2 | 1264 | Ohm | 68240 | GradC | PT1000_3 | 1083 | Ohm | 21433 | GradC | PT1000_4 | 1081 | Ohm | 20916 | GradCCPU_Temperature | 31 | GradC
tick | 130000 | PT1000_1 | 981 | Ohm | -4943 | GradC | PT1000_2 | 1263 | Ohm | 67981 | GradC | PT1000_3 | 1083 | Ohm | 21433 | GradC | PT1000_4 | 1081 | Ohm | 20916 | GradCCPU_Temperature | 31 | GradC
tick | 135000 | PT1000_1 | 982 | Ohm | -4684 | GradC | PT1000_2 | 1263 | Ohm | 67981 | GradC | PT1000_3 | 1084 | Ohm | 21692 | GradC | PT1000_4 | 1081 | Ohm | 20916 | GradCCPU_Temperature | 31 | GradC
tick | 140000 | PT1000_1 | 982 | Ohm | -4684 | GradC | PT1000_2 | 1263 | Ohm | 67981 | GradC | PT1000_3 | 1083 | Ohm | 21433 | GradC | PT1000_4 | 1081 | Ohm | 20916 | GradCCPU_Temperature | 31 | GradC
tick | 145000 | PT1000_1 | 982 | Ohm | -4684 | GradC | PT1000_2 | 1261 | Ohm | 67464 | GradC | PT1000_3 | 1083 | Ohm | 21433 | GradC | PT1000_4 | 1081 | Ohm | 20916 | GradCCPU_Temperature | 31 | GradC
tick | 150000 | PT1000_1 | 982 | Ohm | -4684 | GradC | PT1000_2 | 1263 | Ohm | 67981 | GradC | PT1000_3 | 1083 | Ohm | 21433 | GradC | PT1000_4 | 1081 | Ohm | 20916 | GradCCPU_Temperature | 31 | GradC
tick | 155000 | PT1000_1 | 982 | Ohm | -4684 | GradC | PT1000_2 | 1262 | Ohm | 67723 | GradC | PT1000_3 | 1083 | Ohm | 21433 | GradC | PT1000_4 | 1081 | Ohm | 20916 | GradCCPU_Temperature | 31 | GradC
tick | 160000 | PT1000_1 | 982 | Ohm | -4684 | GradC | PT1000_2 | 1262 | Ohm | 67723 | GradC | PT1000_3 | 1082 | Ohm | 21175 | GradC | PT1000_4 | 1081 | Ohm | 20916 | GradCCPU_Temperature | 31 | GradC
tick | 165000 | PT1000_1 | 981 | Ohm | -4943 | GradC | PT1000_2 | 1262 | Ohm | 67723 | GradC | PT1000_3 | 1083 | Ohm | 21433 | GradC | PT1000_4 | 1082 | Ohm | 21175 | GradCCPU_Temperature | 30 | GradC
tick | 170000 | PT1000_1 | 982 | Ohm | -4684 | GradC | PT1000_2 | 1262 | Ohm | 67723 | GradC | PT1000_3 | 1083 | Ohm | 21433 | GradC | PT1000_4 | 1081 | Ohm | 20916 | GradCCPU_Temperature | 31 | GradC
tick | 175000 | PT1000_1 | 981 | Ohm | -4943 | GradC | PT1000_2 | 1261 | Ohm | 67464 | GradC | PT1000_3 | 1083 | Ohm | 21433 | GradC | PT1000_4 | 1082 | Ohm | 21175 | GradCCPU_Temperature | 31 | GradC
tick | 180000 | PT1000_1 | 982 | Ohm | -4684 | GradC | PT1000_2 | 1262 | Ohm | 67723 | GradC | PT1000_3 | 1083 | Ohm | 21433 | GradC | PT1000_4 | 1081 | Ohm | 20916 | GradCCPU_Temperature | 31 | GradC
tick | 185000 | PT1000_1 | 982 | Ohm | -4684 | GradC | PT1000_2 | 1261 | Ohm | 67464 | GradC | PT1000_3 | 1083 | Ohm | 21433 | GradC | PT1000_4 | 1081 | Ohm | 20916 | GradCCPU_Temperature | 31 | GradC
tick | 190000 | PT1000_1 | 981 | Ohm | -4943 | GradC | PT1000_2 | 1260 | Ohm | 67206 | GradC | PT1000_3 | 1083 | Ohm | 21433 | GradC | PT1000_4 | 1081 | Ohm | 20916 | GradCCPU_Temperature | 31 | GradC
tick | 195000 | PT1000_1 | 981 | Ohm | -4943 | GradC | PT1000_2 | 1261 | Ohm | 67464 | GradC | PT1000_3 | 1083 | Ohm | 21433 | GradC | PT1000_4 | 1081 | Ohm | 20916 | GradCCPU_Temperature | 31 | GradC
tick | 200000 | PT1000_1 | 982 | Ohm | -4684 | GradC | PT1000_2 | 1260 | Ohm | 67206 | GradC | PT1000_3 | 1083 | Ohm | 21433 | GradC | PT1000_4 | 1081 | Ohm | 20916 | GradCCPU_Temperature | 31 | GradC
tick | 205000 | PT1000_1 | 982 | Ohm | -4684 | GradC | PT1000_2 | 1260 | Ohm | 67206 | GradC | PT1000_3 | 1083 | Ohm | 21433 | GradC | PT1000_4 | 1081 | Ohm | 20916 | GradCCPU_Temperature | 31 | GradC
tick | 210000 | PT1000_1 | 981 | Ohm | -4943 | GradC | PT1000_2 | 1260 | Ohm | 67206 | GradC | PT1000_3 | 1082 | Ohm | 21175 | GradC | PT1000_4 | 1081 | Ohm | 20916 | GradCCPU_Temperature | 31 | GradC
tick | 215000 | PT1000_1 | 982 | Ohm | -4684 | GradC | PT1000_2 | 1261 | Ohm | 67464 | GradC | PT1000_3 | 1083 | Ohm | 21433 | GradC | PT1000_4 | 1081 | Ohm | 20916 | GradCCPU_Temperature | 31 | GradC
tick | 220000 | PT1000_1 | 982 | Ohm | -4684 | GradC | PT1000_2 | 1260 | Ohm | 67206 | GradC | PT1000_3 | 1083 | Ohm | 21433 | GradC | PT1000_4 | 1081 | Ohm | 20916 | GradCCPU_Temperature | 31 | GradC
tick | 225000 | PT1000_1 | 981 | Ohm | -4943 | GradC | PT1000_2 | 1257 | Ohm | 66430 | GradC | PT1000_3 | 1083 | Ohm | 21433 | GradC | PT1000_4 | 1081 | Ohm | 20916 | GradCCPU_Temperature | 31 | GradC
tick | 230000 | PT1000_1 | 981 | Ohm | -4943 | GradC | PT1000_2 | 1259 | Ohm | 66947 | GradC | PT1000_3 | 1083 | Ohm | 21433 | GradC | PT1000_4 | 1081 | Ohm | 20916 | GradCCPU_Temperature | 31 | GradC
tick | 235000 | PT1000_1 | 982 | Ohm | -4684 | GradC | PT1000_2 | 1257 | Ohm | 66430 | GradC | PT1000_3 | 1083 | Ohm | 21433 | GradC | PT1000_4 | 1081 | Ohm | 20916 | GradCCPU_Temperature | 31 | GradC
tick | 240000 | PT1000_1 | 980 | Ohm | -5202 | GradC | PT1000_2 | 1258 | Ohm | 66688 | GradC | PT1000_3 | 1083 | Ohm | 21433 | GradC | PT1000_4 | 1081 | Ohm | 20916 | GradCCPU_Temperature | 31 | GradC
tick | 245000 | PT1000_1 | 982 | Ohm | -4684 | GradC | PT1000_2 | 1256 | Ohm | 66171 | GradC | PT1000_3 | 1083 | Ohm | 21433 | GradC | PT1000_4 | 1082 | Ohm | 21175 | GradCCPU_Temperature | 31 | GradC
tick | 250000 | PT1000_1 | 982 | Ohm | -4684 | GradC | PT1000_2 | 1258 | Ohm | 66688 | GradC | PT1000_3 | 1083 | Ohm | 21433 | GradC | PT1000_4 | 1081 | Ohm | 20916 | GradCCPU_Temperature | 31 | GradC
tick | 255000 | PT1000_1 | 981 | Ohm | -4943 | GradC | PT1000_2 | 1259 | Ohm | 66947 | GradC | PT1000_3 | 1083 | Ohm | 21433 | GradC | PT1000_4 | 1081 | Ohm | 20916 | GradCCPU_Temperature | 31 | GradC
tick | 260000 | PT1000_1 | 981 | Ohm | -4943 | GradC | PT1000_2 | 1257 | Ohm | 66430 | GradC | PT1000_3 | 1082 | Ohm | 21175 | GradC | PT1000_4 | 1081 | Ohm | 20916 | GradCCPU_Temperature | 31 | GradC
tick | 265000 | PT1000_1 | 981 | Ohm | -4943 | GradC | PT1000_2 | 1257 | Ohm | 66430 | GradC | PT1000_3 | 1083 | Ohm | 21433 | GradC | PT1000_4 | 1081 | Ohm | 20916 | GradCCPU_Temperature | 31 | GradC
tick | 270000 | PT1000_1 | 982 | Ohm | -4684 | GradC | PT1000_2 | 1258 | Ohm | 66688 | GradC | PT1000_3 | 1083 | Ohm | 21433 | GradC | PT1000_4 | 1082 | Ohm | 21175 | GradCCPU_Temperature | 31 | GradC
tick | 275000 | PT1000_1 | 981 | Ohm | -4943 | GradC | PT1000_2 | 1257 | Ohm | 66430 | GradC | PT1000_3 | 1083 | Ohm | 21433 | GradC | PT1000_4 | 1081 | Ohm | 20916 | GradCCPU_Temperature | 31 | GradC
tick | 280000 | PT1000_1 | 981 | Ohm | -4943 | GradC | PT1000_2 | 1257 | Ohm | 66430 | GradC | PT1000_3 | 1083 | Ohm | 21433 | GradC | PT1000_4 | 1081 | Ohm | 20916 | GradCCPU_Temperature | 31 | GradC
tick | 285000 | PT1000_1 | 981 | Ohm | -4943 | GradC | PT1000_2 | 1256 | Ohm | 66171 | GradC | PT1000_3 | 1083 | Ohm | 21433 | GradC | PT1000_4 | 1081 | Ohm | 20916 | GradCCPU_Temperature | 31 | GradC
tick | 290000 | PT1000_1 | 981 | Ohm | -4943 | GradC | PT1000_2 | 1257 | Ohm | 66430 | GradC | PT1000_3 | 1084 | Ohm | 21692 | GradC | PT1000_4 | 1081 | Ohm | 20916 | GradCCPU_Temperature | 31 | GradC
tick | 295000 | PT1000_1 | 981 | Ohm | -4943 | GradC | PT1000_2 | 1253 | Ohm | 65395 | GradC | PT1000_3 | 1084 | Ohm | 21692 | GradC | PT1000_4 | 1081 | Ohm | 20916 | GradCCPU_Temperature | 31 | GradC
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

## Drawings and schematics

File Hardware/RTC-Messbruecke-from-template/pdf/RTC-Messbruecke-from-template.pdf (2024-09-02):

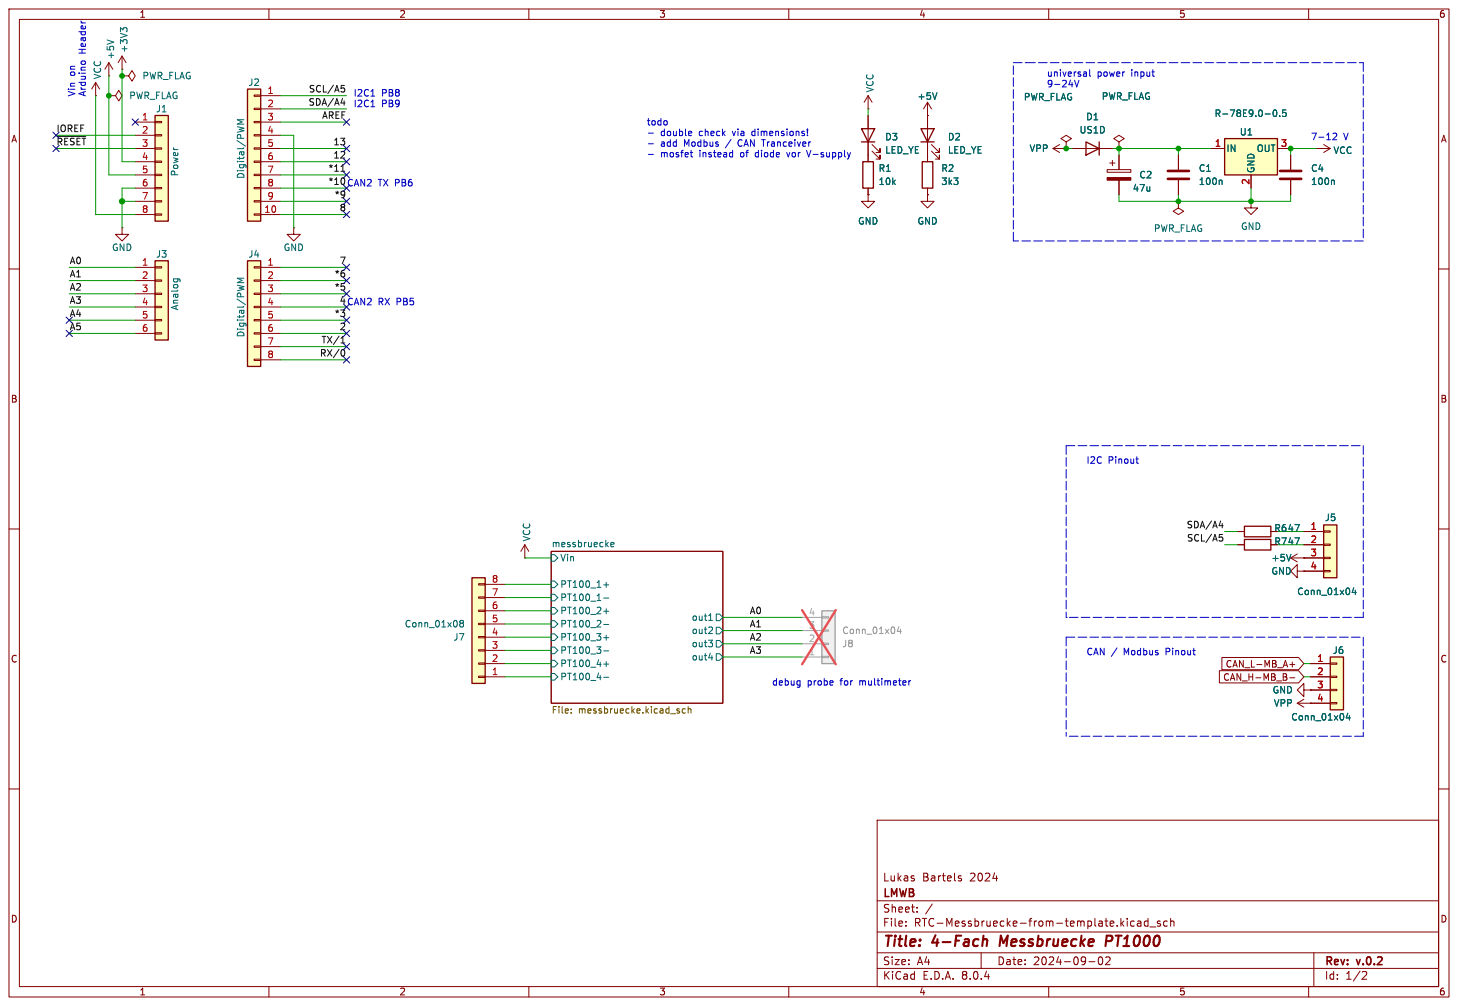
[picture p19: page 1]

*11 Vin on Arduino Header
J7 Conn_01x08 GND+3V3 VCC
VPP +5V

todo
- double check via dimensions! - add Modbus / CAN Tranceiver

- mosfet instead of diode vor V-supply

File: RTC-Messbruecke-from-template.kicad_sch Sheet: / LMWB

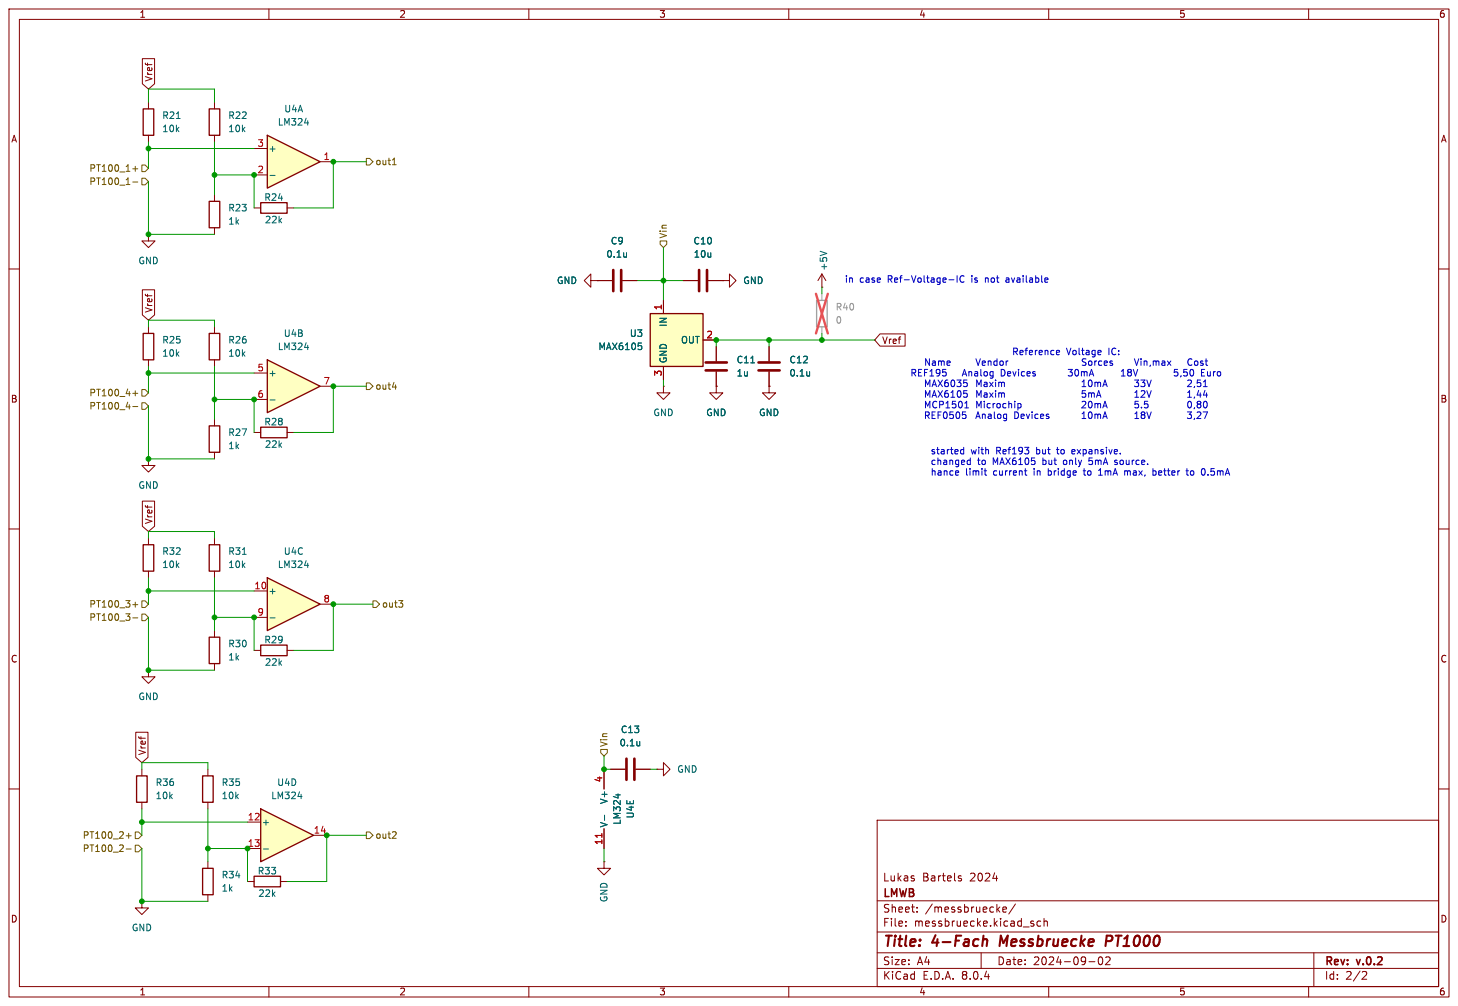
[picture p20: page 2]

started with Ref193 but to expansive.

File: messbruecke.kicad_sch Sheet: /messbruecke/ LMWB

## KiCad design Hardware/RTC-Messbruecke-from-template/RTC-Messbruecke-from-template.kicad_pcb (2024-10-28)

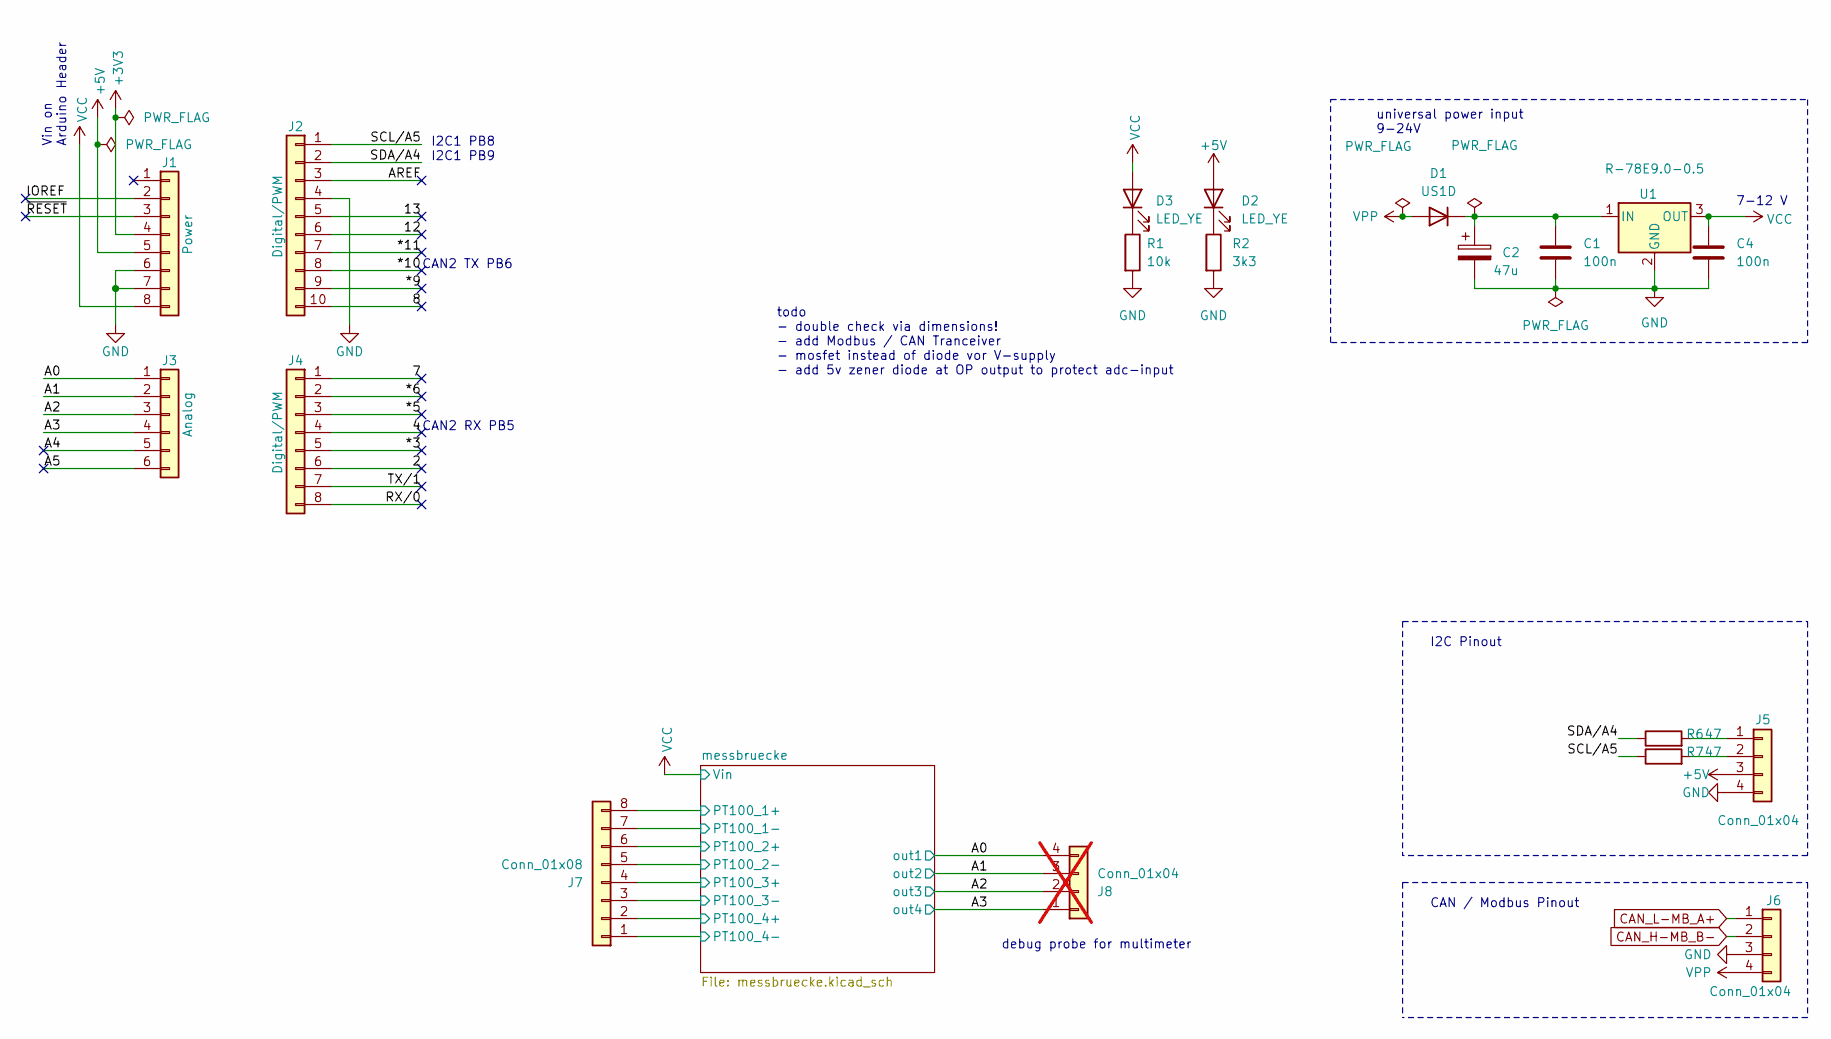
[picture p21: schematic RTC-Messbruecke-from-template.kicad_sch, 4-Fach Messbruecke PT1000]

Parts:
C1, C4: 100n; C_1206_3216Metric_Pad1.33x1.80mm_HandSolder
C2: 47u; CP_Elec_10x12.5
D1: US1D; D_SMA
D2, D3: LED_YE; LED_1210_3225Metric_Pad1.42x2.65mm_HandSolder
J1: Power; PinSocket_1x08_P2.54mm_Vertical
J2: Digital/PWM; PinSocket_1x10_P2.54mm_Vertical
J3: Analog; PinSocket_1x06_P2.54mm_Vertical
J4: Digital/PWM; PinSocket_1x08_P2.54mm_Vertical
J5: Conn_01x04; PinHeader_1x04_P2.54mm_Vertical
J6: Conn_01x04; TerminalBlock_Phoenix_MPT-0,5-4-2.54_1x04_P2.54mm_Horizontal
J7: Conn_01x08; TerminalBlock_Phoenix_MPT-0,5-8-2.54_1x08_P2.54mm_Horizontal
J8: Conn_01x04; TerminalBlock_Phoenix_MPT-0,5-4-2.54_1x04_P2.54mm_Horizontal; not fitted
R1: 10k; R_1206_3216Metric_Pad1.30x1.75mm_HandSolder
R2: 3k3; R_1206_3216Metric_Pad1.30x1.75mm_HandSolder
R6, R7: 47; R_1206_3216Metric_Pad1.30x1.75mm_HandSolder
U1: R-78E9.0-0.5; Converter_DCDC_RECOM_R-78E-0.5_THT

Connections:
+3V3: J1.4
+5V: D2.2 (A), J1.5, J5.3; also elsewhere on the board
/2: J4.6
/4: J4.4
/7: J4.1
/8: J2.10
/12: J2.6
/13: J2.5
/*3: J4.5
/*5: J4.3
/*6: J4.2
/*9: J2.9
/*10: J2.8
/*11: J2.7
/A0: J3.1, J8.4; also elsewhere on the board
/A1: J3.2, J8.3; also elsewhere on the board
/A2: J3.3, J8.2; also elsewhere on the board
/A3: J3.4, J8.1; also elsewhere on the board
/A4: J3.5
/A5: J3.6
/AREF: J2.3
/IOREF: J1.2
/RX/0: J4.8
/SCL/A5: J2.1, R7.1
/SDA/A4: J2.2, R6.1
/TX/1: J4.7
/messbruecke/PT100_1+: J7.8; also elsewhere on the board
/messbruecke/PT100_2+: J7.6; also elsewhere on the board
/messbruecke/PT100_3+: J7.4; also elsewhere on the board
/messbruecke/PT100_4+: J7.2; also elsewhere on the board
/~RESET: J1.3
CAN_H-MB_B-: J6.2
CAN_L-MB_A+: J6.1
GND: C1.2, C2.2, C4.2, J1.6, J1.7, J2.4, J5.4, J6.3, J7.1, J7.3, J7.5, J7.7, R1.2, R2.2, U1.2 (GND); also elsewhere on the board
unnamed: C1.1, C2.1, D1.1 (K), U1.1 (IN)
unnamed: D2.1 (K), R2.1
unnamed: D3.1 (K), R1.1
unnamed: J5.1, R6.2
unnamed: J5.2, R7.2
VCC: C4.1, D3.2 (A), J1.8, U1.3 (OUT); also elsewhere on the board
VPP: D1.2 (A), J6.4

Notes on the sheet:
Vin on Arduino Header
I2C1 PB8 I2C1 PB9
7-12 V
CAN / Modbus Pinout
CAN2 RX PB5
CAN2 TX PB6
I2C Pinout
todo - double check via dimensions! - add Modbus / CAN Tranceiver - mosfet instead of diode vor V-supply - add 5v zener diode at OP output to protect adc-input
debug probe for multimeter
universal power input 9-24V

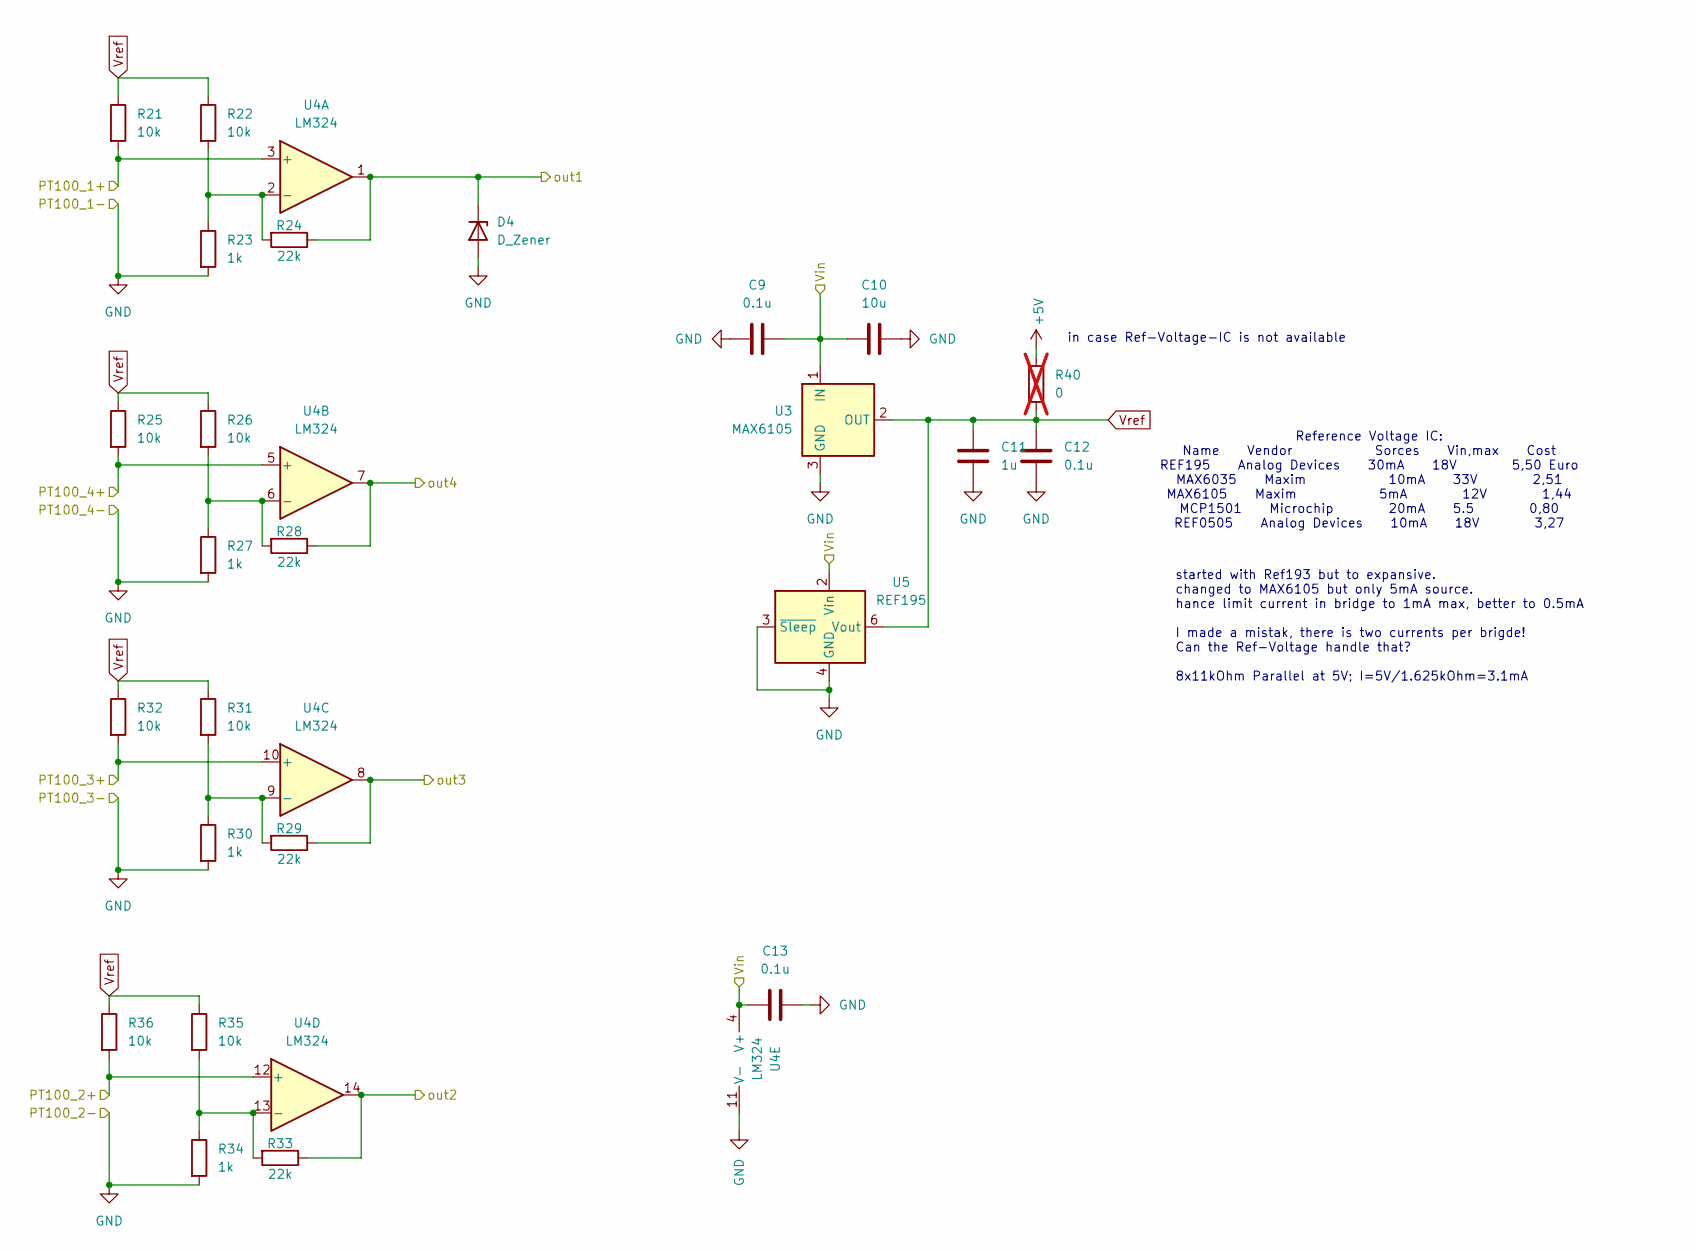
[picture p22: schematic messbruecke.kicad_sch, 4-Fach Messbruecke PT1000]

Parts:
C9, C12, C13: 0.1u; C_1206_3216Metric
C10: 10u; C_1206_3216Metric
C11: 1u; C_1206_3216Metric
D4: D_Zener; D_1206_3216Metric
R21, R22, R25, R26, R31, R32, R35, R36: 10k; R_1206_3216Metric
R23, R27, R30, R34: 1k; R_1206_3216Metric
R24, R28, R29, R33: 22k; R_1206_3216Metric
R40: 0; R_1206_3216Metric; not fitted
U3: MAX6105; SOT-23
U4: LM324; SOIC-14_3.9x8.7mm_P1.27mm
U5: REF195; SOIC-8_3.9x4.9mm_P1.27mm

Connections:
+5V: R40.1; also elsewhere on the board
/A0: D4.1 (K), R24.1, U4.1; also elsewhere on the board
/A1: R33.1, U4.14; also elsewhere on the board
/A2: R29.1, U4.8; also elsewhere on the board
/A3: R28.1, U4.7; also elsewhere on the board
/messbruecke/PT100_1+: R21.2, U4.3 (+); also elsewhere on the board
/messbruecke/PT100_2+: R36.2, U4.12 (+); also elsewhere on the board
/messbruecke/PT100_3+: R32.2, U4.10 (+); also elsewhere on the board
/messbruecke/PT100_4+: R25.2, U4.5 (+); also elsewhere on the board
GND: C9.2, C10.2, C11.2, C12.2, C13.2, D4.2 (A), R23.2, R27.2, R30.2, R34.2, U3.3 (GND), U4.11 (V-), U5.3 (~Sleep), U5.4 (GND); also elsewhere on the board
unnamed: R22.2, R23.1, R24.2, U4.2 (-)
unnamed: R26.2, R27.1, R28.2, U4.6 (-)
unnamed: R29.2, R30.1, R31.2, U4.9 (-)
unnamed: R33.2, R34.1, R35.2, U4.13 (-)
VCC: C9.1, C10.1, C13.1, U3.1 (IN), U4.4 (V+), U5.2 (Vin); also elsewhere on the board
Vref: C11.1, C12.1, R21.1, R22.1, R25.1, R26.1, R31.1, R32.1, R35.1, R36.1, R40.2, U3.2 (OUT), U5.6 (Vout)

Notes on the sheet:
in case Ref-Voltage-IC is not available
started with Ref193 but to expansive. changed to MAX6105 but only 5mA source. hance limit current in bridge to 1mA max, better to 0.5mA I made a mistak, there is two currents per brigde! Can the Ref-Voltage handle that? 8x11kOhm Parallel at 5V; I=5V/1.625kOhm=3.1mA
Reference Voltage IC: Name Vendor Sorces Vin,max Cost REF195 Analog Devices 30mA 18V 5,50 Euro MAX6035 Maxim 10mA 33V 2,51 MAX6105 Maxim 5mA 12V 1,44 MCP1501 Microchip 20mA 5.5 0,80 REF0505 Analog Devices 10mA 18V 3,27

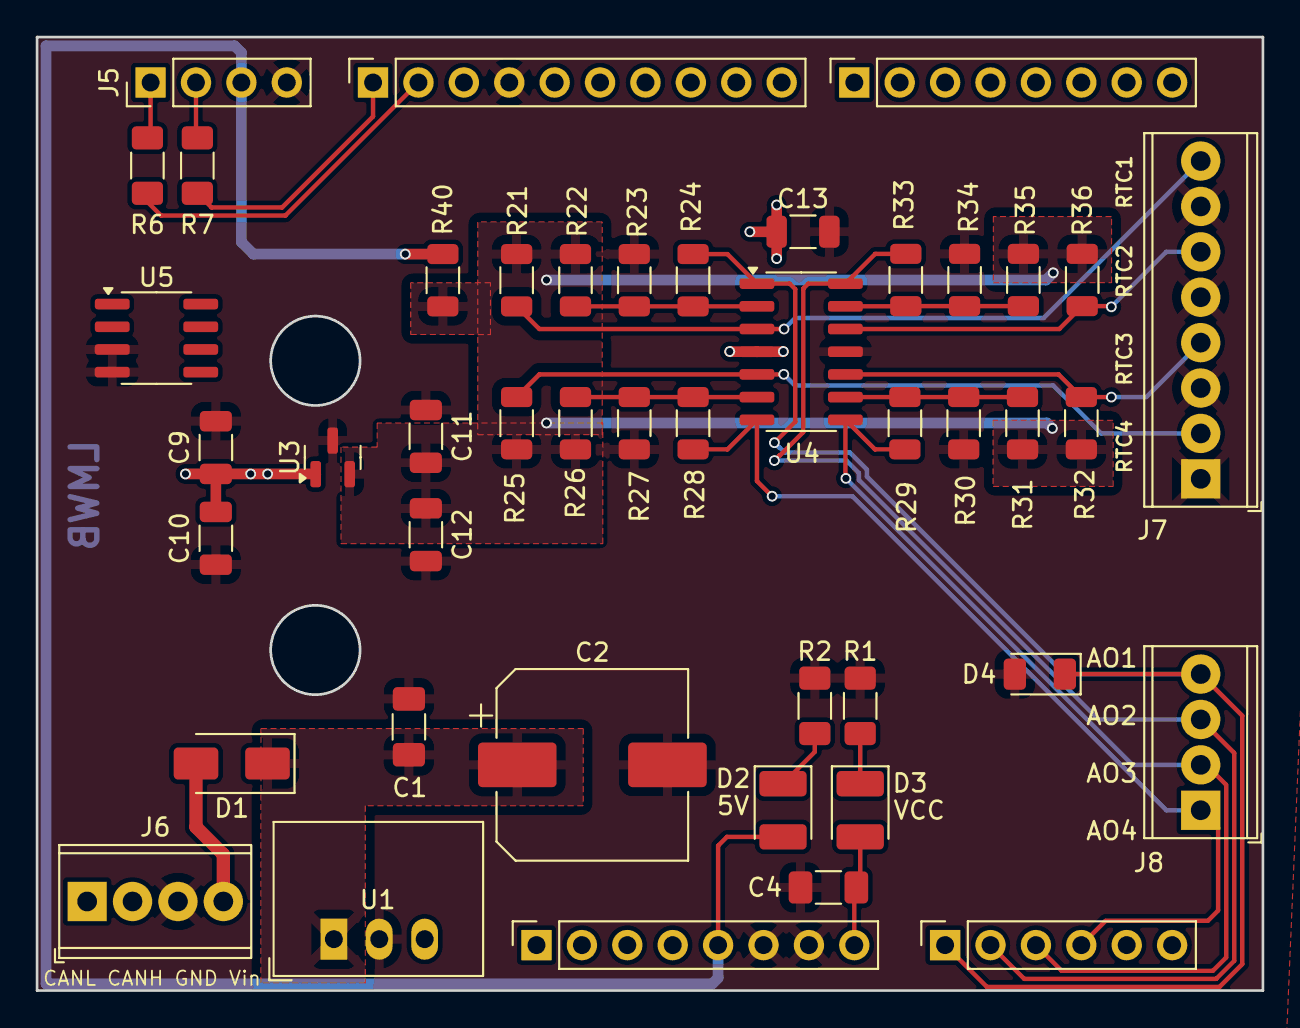
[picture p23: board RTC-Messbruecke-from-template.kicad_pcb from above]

Board: 2 copper layers, 68.6 x 53.3 mm, 45 parts (0 on the bottom side), 24 nets.

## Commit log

2024-08-25 added a lot of files
    [RTC-Messbruecke-from-template-B_Cu.gbl, RTC-Messbruecke-from-template-B_Mask.gbs, RTC-Messbruecke-from-template-B_Paste.gbp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]
2024-09-02 added picture intext, renamed folder
    [pt1000.ods]
2024-09-02 make shure octave simulation will work, deleted unnecessary files
    [pt1000.ods]
2024-09-02 added picture of schematic
    [messbruecke.kicad_sch]
2024-09-02 modified readme
    [RTC-Messbruecke-from-template.kicad_sch, messbruecke.kicad_sch]
2024-09-02 clear gitignor, deleted kicad backups
2024-09-23 added test results and simulations
    [RTC-Messbruecke-from-template.kicad_pcb, RTC-Messbruecke-from-template.kicad_sch, ds18b20-log.csv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]
2024-10-28 added REF-195 as alternativ voltage reference
    [RTC-Messbruecke-from-template.kicad_pcb, messbruecke.kicad_sch]
2024-12-03 added BOM
2025-01-16 spice model to map from -20..+80 deg.C
    [messbruecke-r-network-dimension.ods]
